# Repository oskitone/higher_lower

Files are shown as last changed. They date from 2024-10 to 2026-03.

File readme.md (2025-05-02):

# Higher Lower

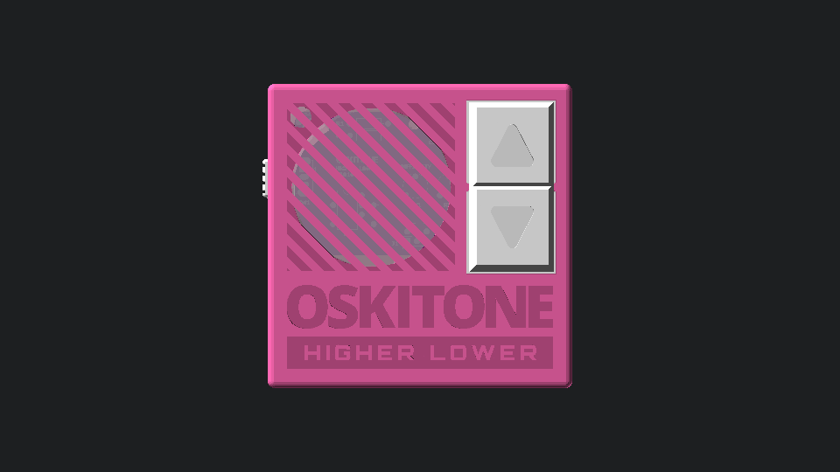
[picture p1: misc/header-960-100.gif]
Higher Lower game model animation


Higher Lower is a 3D-printed, screen-free, handheld electronic game about arbitrary musical intervals.

**DIY electronics kit:** [https://www.oskitone.com/product/higher-lower-game-diy-electronics-kit](https://www.oskitone.com/product/higher-lower-game-diy-electronics-kit)  
**Gameplay demo:** [https://vimeo.com/1075918437](https://vimeo.com/1075918437)  
**Assembly guide:** [https://oskitone.github.io/higher_lower](https://oskitone.github.io/higher_lower)

Obviously, I'd prefer you buy the kit from me. But, if circumstances prohibit, I've uploaded the [Higher Lower PCB to OSH Park](https://oshpark.com/shared_projects/yGNulCRo); please buy it from them with my blessing.

## How to play "Higher Lower"

Two different tones play. Is the second tone _higher_ or _lower_ than the first? The more guesses you get right, the harder it gets!

- Four guesses per round, ten rounds per game. Any wrong guess and the game resets.
- Your score is how many rounds have passed, and it's announced after each round as a series of happy trill noises.
- For a multiplayer game, hand off to the next player after each round. The last player to successfully complete their round wins.
- At the start of each new game, the "Higher Lower" theme song plays. It is a very good song.
- Upon completing all ten rounds of guesses and winning the game, the theme plays again, faster and _faster_ and **_faster_** until the machine finally resets into a new game at a harder difficulty setting.
- Adjust volume and game difficulty by opening the enclosure and adjusting trim potentiometers on the PCB.

## Schematic

Higher Lower schematic

In pursuit of a small BOM and quick assembly, there are a few concessions:

- There's no amplifier, just the IC to volume pot to cap to speaker. In theory, the speaker can draw more current than the chip can supply, causing it to overheat. In practice, it hasn't been an issue.
- There's a small .1uF bypass cap to smooth out power supply noise. Normally there's a big one too like the Scout's 220uF electrolytic cap. Again, in practice, its absence hasn't been an issue.

## Running, deploying

    ./run.sh -h

Requires arduino-cli to compile, [Ardens](https://github.com/tiberiusbrown/Ardens) to emulate, then a [Sparkfun programmer](https://www.sparkfun.com/products/9825) to upload. (Other programmers may work just as well, but I've only tested this one.)

### Deployment troubleshooting

- `Could not find USBtiny device`: Programmer not connected?
- `Programmer operation not supported`: Make sure board is getting full power. Try setting "CTRL" pot to its middle value. (Some pins to programmer are shared with game inputs.)

### Arduboy

You can also deploy to an [Arduboy](https://www.arduboy.com/) using the Arduino IDE. Play using the device's Up/Down buttons.

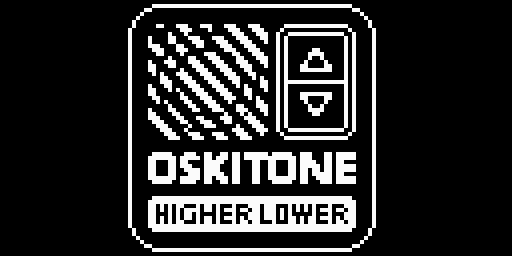
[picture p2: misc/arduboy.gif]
Higher Lower on Arduboy


(And you can play an online emulation of "Higher Lower" on the Arduboy [here](https://tiberiusbrown.github.io/Ardens/player.html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)!)

## 3D Models

higher_lower's 3D-printed models are written in OpenSCAD.

### Dependencies

Assumes `parts_cafe` and `scout` repos are in sibling directories and are _both up to date_ on the `main` branch. Here's how I've got it:

    \ oskitone
        \ higher_lower
        \ parts_cafe
        \ scout

You'll also need to install the [Orbitron](https://fonts.google.com/specimen/Orbitron) font.

### Building

STLs are generated with `make_stls.sh`. Run `./make_stls.sh -h` for full flags list.

## License

Designed by Oskitone. Please support future projects by purchasing from [Oskitone](https://www.oskitone.com/).

Creative Commons Attribution/Share-Alike, all text above must be included in any redistribution. See license.txt for additional details.

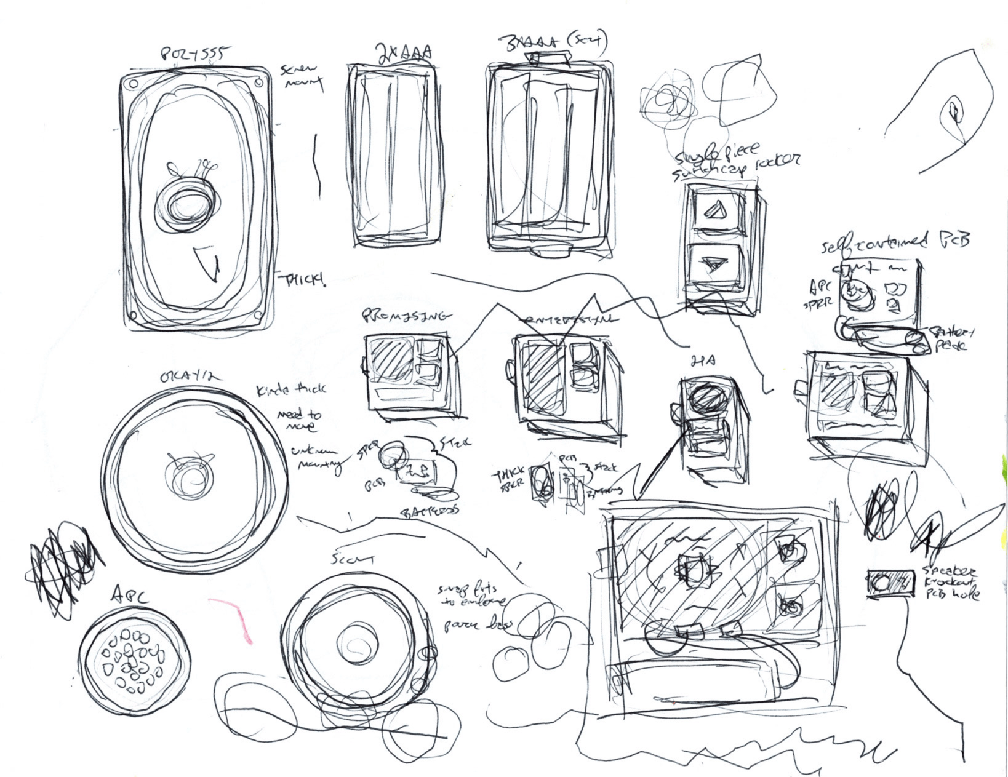
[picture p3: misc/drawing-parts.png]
Drawing, traces of speakers and batteries, prospective enclosure layouts


(drawing by me and my son)

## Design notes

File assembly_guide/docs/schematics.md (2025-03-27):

---
id: schematics
title: Schematics
description: Higher Lower circuit schematics
sidebar_label: Schematics
image: /img/final_product_1-004.jpg
hide_table_of_contents: true
---

Higher Lower schematic

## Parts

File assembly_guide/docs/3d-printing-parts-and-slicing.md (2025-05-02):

---
id: 3d-printing-parts-and-slicing
title: 3D-Printing
description: How to 3D-print your Higher Lower's parts.
sidebar_label: 3D-Printing
image: /img/3d_printed_parts.jpg
slug: /3d-printing-parts-and-slicing
---

:::note
If you bought a kit with 3D-printed parts included, you can skip this section, but do [open up the enclosure](opening-the-enclosure.md) and confirm you have all the right pieces ready before continuing.
:::

## Download

Download STLs of the models from [Printables](https://www.printables.com/model/1283695-higher-lower-handheld-electronic-game) or [Thingiverse](https://www.thingiverse.com/thing:7027239).

Higher Lower

## Slicing

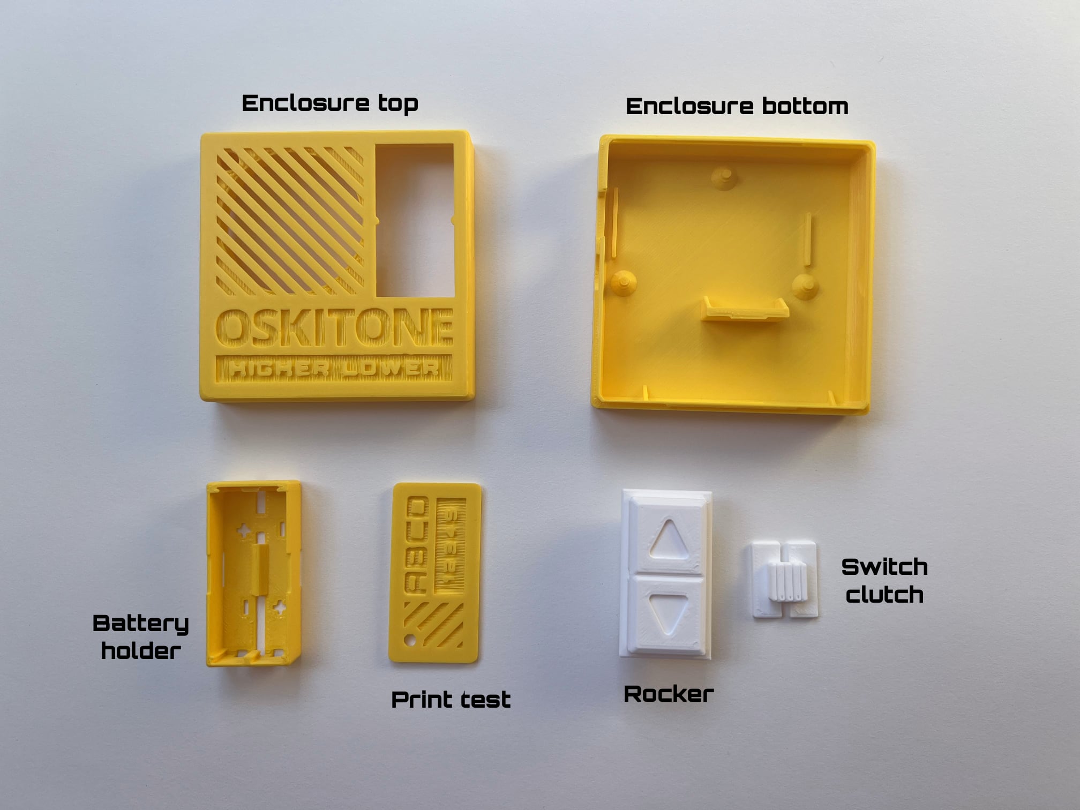
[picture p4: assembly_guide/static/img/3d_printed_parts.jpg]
3D-printed parts


There are six files to print, but only five are required. They'll take a little over four hours total.

| Part | Layer Height | Supports? | Estimated Time |
| --- | --- | --- | --- |
| enclosure_top | .2mm | No | 1.5hr |
| enclosure_bottom | .2mm | No | 1.5hr |
| battery_holder | .2mm | No | 30min |
| print_test (optional) | .2mm | No | 15min |
| rocker | .2mm | No | 30min |
| switch_clutch | .2mm | No | 10min |

:::info Optional but recommended
The `print_test` STL isn't used in assembly but is included to verify your printer's calibration and slicer settings. It's recommended to print it first before committing to the rest of the parts.
:::

The enclosure has engravings that print on the build plate and bridge on top. Adjust your slicer's bridging angle so they run up and down with the text:

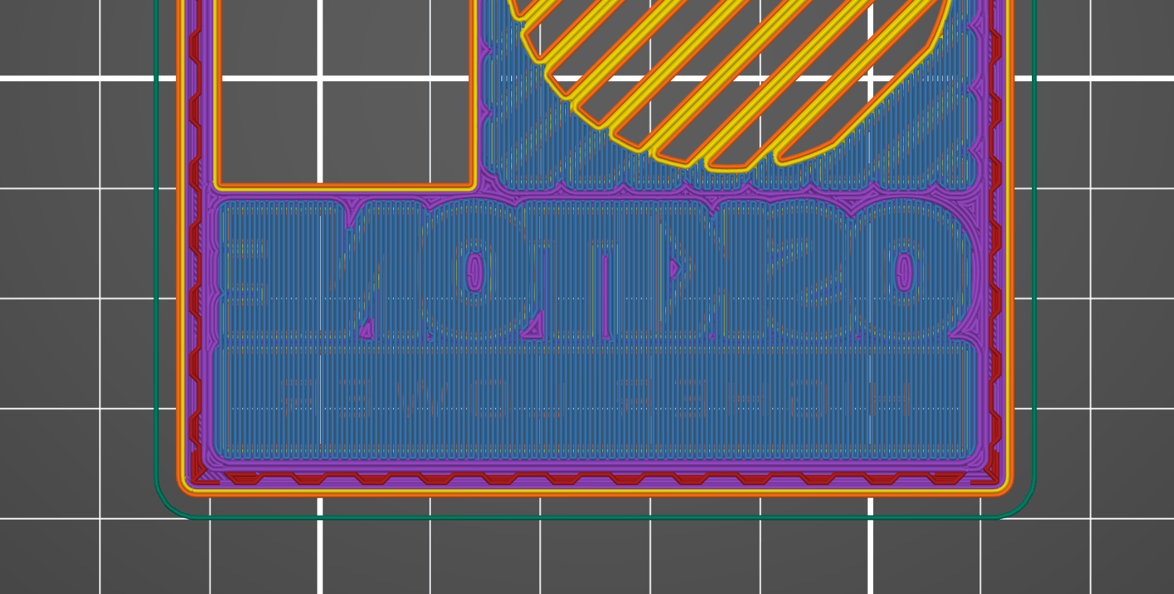
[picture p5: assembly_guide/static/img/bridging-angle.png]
bridging angle set correct


**Other notes:**

- Models assume Fused Deposition Modeling with a standard .4mm nozzle. Using a bigger nozzle will likely result in a loss of detail.
- The 3D-printed parts were designed using PLA. Other filament types like ABS are not recommended and will likely have fit or tolerance issues. (If you find that you need to drill or file your prints, that's a good sign there'll be other problems too.)
- 20% infill works well across all models.
- Any supports the models need they'll already have, they'll already be rotated to the correct orientation for printing, and they shouldn't need brims.
- Watch the first couple layers of the enclosure pieces while printing, especially around the text engravings -- if you see bad adhesion, stop the print to remedy the situation and start again.
- If the prints aren't fitting together well, check to see that the corners aren't bulging. See if your slicer has settings for "coasting" or "linear advance."

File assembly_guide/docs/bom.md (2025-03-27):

---
id: bom
title: Annotated BOM
description: Bill of Materials, annotated.
sidebar_label: Annotated BOM
slug: /bom
image: /img/kit_parts.jpg
hide_table_of_contents: true
---

| Designator | Quantity | Designation | Marking | Footprint |
| --- | --- | --- | --- | --- |
| C1 | 1 | .1uF | 104 | C_Disc_D5.0mm_W2.5mm_P5.00mm |
| C2 | 1 | 220uF | | CP_Radial_D8.0mm_P3.50mm |
| D1 | 1 | LED_RKGB | | LED_D5.0mm-4_RGB_Staggered_Pins |
| J1 | 1 | Conn_02x03 | | PinHeader_2x03_P2.54mm_Vertical |
| LS1 | 1 | AZ40R | | 40mm x 5mm |
| R1,R2 | 2 | 1k | Brown Black Red | R_Axial_DIN0207_L6.3mm_D2.5mm_P10.16mm_Horizontal |
| RV1 | 1 | 10k | 103 | Potentiometer_Piher_PT-6-V_Vertical-mirror |
| RV2 | 1 | 1k | 102 | Potentiometer_Piher_PT-6-V_Vertical-mirror |
| SW1 | 1 | SW_SPDT | | SW_Slide_SPDT_Angled_CK_OS102011MA1Q |
| SW2,SW3 | 2 | SW_SPST | | SW_PUSH_6mm |
| U1 | 1 | ATTINY85V + socket | | DIP-8_W7.62mm |

Also:

- 10" of 2-wire ribbon cables (or similar _small_ gauge, stranded wire)
  - 5" for BT1
  - 5" for LS1
- 4 battery terminal contacts for battery holder
  - 1 dual spring+button wire contacts (Keystone 181)
  - 1 tabbed spring contact (Keystone 5204)
  - 1 tabbed button contact (Keystone 5226)
- LED lightpipe
  - Hot glue stick, standard 1/4" diameter, cut to 1/8" length
  - An inch or so of electrical tape

Alternate speakers for the AZ40R:

- PSR-40N08A05-JQ
- AS04008MR-21-R
- CMS-4051-058SP

Any circular 8ohm speaker that matches the dimensions will probably work, thought you may find you need a bit of hot glue to hold it in place.

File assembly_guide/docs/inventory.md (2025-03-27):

---
id: inventory
title: Inventory
description: What you'll need to gather before getting started.
sidebar_label: Inventory
image: /img/kit_parts.jpg
slug: /inventory
---

#### Required

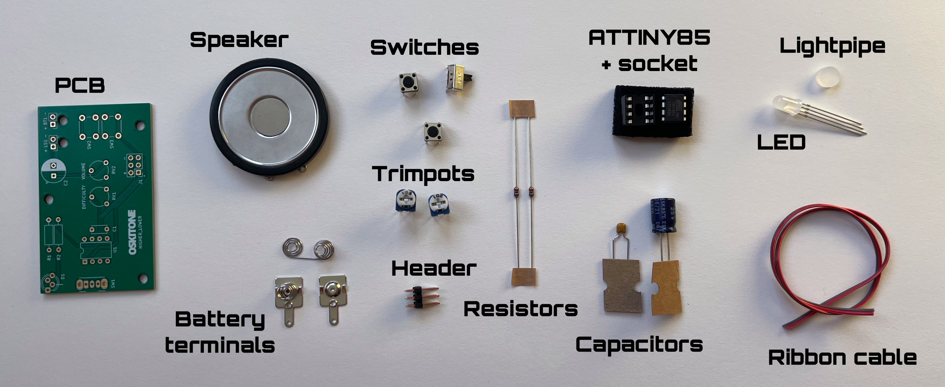
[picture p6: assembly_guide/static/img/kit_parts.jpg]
Higher Lower Game DIY Electronics Kit parts


- [Higher Lower Game DIY Electronics Kit](https://www.oskitone.com/product/higher-lower-game-diy-electronics-kit), 20 parts total
  - 1 PCB
  - 1 Speaker
  - 3 Battery terminals
  - 3 Switches
  - 2 Trimpots
  - 1 Header
  - 2 Resistors
  - 1 ATtiny85 chip + 1 chip socket
  - 2 Capacitors
  - 1 Lightpipe
  - 1 LED
  - 1 Ribbon cable
- [3D-printed parts](3d-printing-parts-and-slicing), 5 parts total
  - battery holder
  - enclosure bottom
  - enclosure top
  - rocker
  - switch clutch
- Soldering iron and solder specifically for electronics
- Wire stripper or cutters
- 2 AAA batteries

#### Recommended

- Needle nose pliers
- Multimeter for debugging
- PCB vice or “helping hands” holder
- “Solder sucker” or desoldering braid
- Black electrical tape
- Patience, patience, patience

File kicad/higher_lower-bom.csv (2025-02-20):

Id | Designator | Footprint | Quantity | Designation | Supplier and ref
1 | SW2,SW3 | SW_PUSH_6mm | 2 | SW_SPST
2 | C1 | C_Disc_D5.0mm_W2.5mm_P5.00mm | 1 | .1uF
3 | LS1 | PinHeader_1x02_P2.54mm_Vertical | 1 | Speaker
4 | U1 | DIP-8_W7.62mm | 1 | ATTINY85V-10PU
5 | SW1 | SW_Slide_SPDT_Angled_CK_OS102011MA1Q | 1 | SW_SPDT
6 | BT1 | PinHeader_1x02_P2.54mm_Vertical | 1 | 1.8V-5.5V
7 | D1 | LED_D5.0mm-4_RGB_Staggered_Pins | 1 | LED_RKGB
8 | RV2 | Potentiometer_Piher_PT-6-V_Vertical-mirror | 1 | 1k
9 | Ref** | branding-15mm_wide | 1 | Val**
10 | RV1 | Potentiometer_Piher_PT-6-V_Vertical-mirror | 1 | 10k
11 | C2 | CP_Radial_D8.0mm_P3.50mm | 1 | 220uF
12 | J1 | PinHeader_2x03_P2.54mm_Vertical | 1 | Conn_02x03
13 | R2,R1 | R_Axial_DIN0207_L6.3mm_D2.5mm_P10.16mm_Horizontal | 2 | 1k

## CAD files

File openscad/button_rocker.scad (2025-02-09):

include <../../parts_cafe/openscad/cap_blank.scad>;
include <../../parts_cafe/openscad/engraving.scad>;
include <../../parts_cafe/openscad/flat_top_rectangular_pyramid.scad>;

// NOTES: must be well less than SCOUT_DEFAULT_GUTTER,
// chamfer is eyeballed against ENCLOSURE_INNER_CHAMFER
ROCKER_BRIM_SIZE = 2;
ROCKER_BRIM_HEIGHT = 1.2;
ROCKER_BRIM_CHAMFER = .6;

BUTTON_ROCKER_TOP_CHAMFER = 2;

ROCKER_ENCLOSURE_FIXTURE_DEPTH = .4;

function get_rocker_switch_center(
    xy = [0,0],
    offset = [0,0]
) = ([
    xy.x - offset.x,
    xy.y - offset.y,
]);

module button_rocker(
    width, length, height,

    switch_centers = [],
    actuator_cavity_height =
        SPST_ACTUATOR_HEIGHT_OFF_PCB - SPST_BASE_DIMENSIONS.z
        - SPST_CONSERVATIVE_TRAVEL,

    plunge = 0,

    xy_clearance = 0,
    z_clearance = 0,

    brim_size = ROCKER_BRIM_SIZE,
    brim_height = ROCKER_BRIM_HEIGHT,
    brim_chamfer = ROCKER_BRIM_CHAMFER,

    fixture_retraction = 0,
    fixture_cavity_height = 2,

    fillet = 0,
    chamfer = ENCLOSURE_ENGRAVING_CHAMFER,

    tolerance = 0,

    outer_color = undef,
    cavity_color = undef,

    quick_preview = false
) {
    e = .0481;

    brim_dimensions = [
        width + brim_size * 2,
        length * 2 + xy_clearance + brim_size * 2,
        brim_height
    ];

    actuator_cavitiy_inner_diameter = SPST_ACTUATOR_DIAMETER
        + tolerance * 4; // NOTE: doubled to be intentionally loose
    actuator_cavitiy_outer_diameter = actuator_cavitiy_inner_diameter + chamfer * 2;

    minimum_walled_actuator_cavities_width =
        actuator_cavitiy_outer_diameter + ENCLOSURE_INNER_WALL * 2;

    plunge = plunge + actuator_cavity_height;
    offset = min(
        (brim_dimensions.x - minimum_walled_actuator_cavities_width) / 2,
        plunge // ie, a 45 degree chamfer
    );

    module _engraving(y, rotation, size = min(width, length) * .5) {
        translate([width / 2, y, height - ENCLOSURE_ENGRAVING_DEPTH]) {
            rotate([0, 0, rotation]) engraving(
                svg = "../misc/arrow.svg",
                resize = [size, size],
                bleed = quick_preview ? 0 : ENCLOSURE_ENGRAVING_BLEED,
                height = ENCLOSURE_ENGRAVING_DEPTH + e,
                center = true,
                chamfer =  quick_preview ? 0 : chamfer
            );
        }
    }

    module _actuator_cavities($fn = quick_preview ? 6 : 24) {
        for (xy = switch_centers) {
            translate([xy.x, xy.y, -(plunge + e)]) {
                cylinder(
                    d = actuator_cavitiy_inner_diameter,
                    h = actuator_cavity_height + e
                );

                cylinder(
                    d1 = actuator_cavitiy_outer_diameter,
                    d2 = actuator_cavitiy_inner_diameter,
                    h = chamfer + e
                );
            }
        }
    }

    module _enclosure_fixture_cavity() {
        radius = ROCKER_ENCLOSURE_FIXTURE_DEPTH + fixture_retraction
            + tolerance * 4; // NOTE: again, doubled to be intentionally loose

        for (x = [-(fixture_retraction + tolerance), width + fixture_retraction]) {
            translate([x, length + xy_clearance / 2, brim_dimensions.z]) {
                cylinder(
                    r = radius,
                    h = fixture_cavity_height,
                    $fn = 8
                );
            }
        }
    }

    difference() {
        color(outer_color) {
            for (y = [0, length + xy_clearance]) {
                translate([0, y, -e]) {
                    cap_blank(
                        dimensions = [width, length, height + e],
                        contact_dimensions = [
                            width - SCOUT_DEFAULT_GUTTER,
                            length - SCOUT_DEFAULT_GUTTER,
                            BUTTON_ROCKER_TOP_CHAMFER
                        ],

                        fillet = fillet
                    );
                }
            }

            translate([-brim_size, -brim_size, 0]) {
                cube([
                    brim_dimensions.x,
                    brim_dimensions.y,
                    brim_dimensions.z - brim_chamfer + e
                ]);

                translate([0, 0, brim_dimensions.z - brim_chamfer]) {
                    flat_top_rectangular_pyramid(
                        top_width = brim_dimensions.x - brim_chamfer * 2,
                        top_length = brim_dimensions.y - brim_chamfer * 2,
                        bottom_width = brim_dimensions.x,
                        bottom_length = brim_dimensions.y,
                        height = brim_chamfer
                    );
                }
            }

            translate([-brim_size + offset, -brim_size + offset, -plunge]) {
                flat_top_rectangular_pyramid(
                    top_width = brim_dimensions.x,
                    top_length = brim_dimensions.y,
                    bottom_width = brim_dimensions.x - offset * 2,
                    bottom_length = brim_dimensions.y - offset * 2,
                    height = plunge + e
                );
            }
        }

        color(cavity_color) {
            _engraving(length + xy_clearance + length / 2, 0);
            _engraving(length / 2, 180);
            _actuator_cavities();
            _enclosure_fixture_cavity();
        }
    }
}

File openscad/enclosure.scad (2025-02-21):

include <../../parts_cafe/openscad/battery_holder_fixtures.scad>;
include <../../parts_cafe/openscad/diagonal_grill.scad>;
include <../../parts_cafe/openscad/enclosure_engraving.scad>;
include <../../parts_cafe/openscad/enclosure.scad>;
include <../../parts_cafe/openscad/flat_top_rectangular_pyramid.scad>;
include <../../parts_cafe/openscad/pcb_mounting_columns.scad>;
include <../../parts_cafe/openscad/ring.scad>;

include <pcb.scad>;

SWITCH_CLUTCH_GRIP_LENGTH = 10;

DEFAULT_ROUNDING = 24;
HIDEF_ROUNDING = 120;

module enclosure(
    show_top = true,
    show_bottom = true,

    dimensions = [0,0,0],
    bottom_height = 0,
    top_height = 0,

    control_clearance = 0,

    pcb_position = [0,0,0],
    led_position_on_pcb = PCB_LED_POSITION,

    speaker_position = [0,0,0],
    speaker_grill_dimensions = [0,0,0],
    speaker_grill_position = [0,0,0],

    lightpipe_position = [0,0],

    button_dimensions = [0,0],
    button_rocker_position = [0,0,0],
    rocker_xy_clearance = 0,

    battery_holder_dimensions = [0,0,0],
    battery_holder_position = [0,0,0],

    label_gutter = 0,

    top_engraving_dimensions = [0,0],
    top_engraving_position = [0,0],
    top_engraving_model_text_size = 3.8,
    top_engraving_model_length = ENCLOSURE_ENGRAVING_LENGTH,

    lip_height = ENCLOSURE_LIP_HEIGHT,

    fillet = ENCLOSURE_FILLET,
    inner_chamfer = ENCLOSURE_INNER_CHAMFER,

    pcb_width = 0,
    pcb_length = 0,
    pcb_height = PCB_HEIGHT,

    pcb_post_hole_positions = [],

    switch_clutch_grip_height = 0,
    switch_clutch_web_length_extension = 0,

    tolerance = 0,

    outer_color = undef,
    cavity_color = undef,

    chamfer = .4,
    show_dfm = true,

    quick_preview = true
) {
    e = .03183;

    cavity_z = dimensions.z - ENCLOSURE_FLOOR_CEILING - e;
    cavity_height = ENCLOSURE_FLOOR_CEILING + e * 2;

    speaker_cavity_diameter = SPEAKER_DIAMETER + tolerance * 2;

    switch_clutch_aligner_length =
        SWITCH_CLUTCH_GRIP_LENGTH + SWITCH_ACTUATOR_TRAVEL
        + switch_clutch_web_length_extension * 2;
    switch_clutch_aligner_y = pcb_position.y + PCB_SWITCH_Y
            + SWITCH_BASE_LENGTH / 2
            - switch_clutch_aligner_length / 2;

    under_pcb_fixture_height = pcb_position.z - ENCLOSURE_FLOOR_CEILING;

    module _c(
        diameter,
        height,
        chamfer = chamfer,
        $fn = quick_preview ? undef : HIDEF_ROUNDING
    ) {
        cylinder(
            d = diameter,
            h = height
        );

        if (show_dfm && chamfer > 0) {
            translate([0, 0, height - chamfer]) {
                cylinder(
                    d1 = diameter,
                    d2 = diameter + chamfer * 2,
                    h = chamfer
                );
            }
        }
    }

    module _speaker_grill(
        depth = ENCLOSURE_ENGRAVING_DEPTH
    ) {
        translate([
            speaker_grill_position.x,
            speaker_grill_position.y,
            dimensions.z - depth
        ]) {
            render() diagonal_grill(
                speaker_grill_dimensions.x,
                speaker_grill_dimensions.y,
                depth + e,
                size = DIAGONAL_GRILL_SIZE
            );
        }
    }

    module _speaker_cavity() {
        z = dimensions.z - ENCLOSURE_FLOOR_CEILING;

        render() intersection() {
            translate([speaker_position.x, speaker_position.y, z - e]) {
                _c(
                    speaker_cavity_diameter,
                    ENCLOSURE_FLOOR_CEILING + e * 2,
                    chamfer = 0
                );
            }

            _speaker_grill(ENCLOSURE_FLOOR_CEILING + e * 2);
        }
    }

    module _bottom_engraving(
        brand_length = 8,
        make_y = dimensions.y * .25
    ) {
        render() enclosure_engraving(
            size = brand_length,
            center = true,
            position = [dimensions.x / 2, make_y],
            bottom = true,
            quick_preview = quick_preview,
            enclosure_height = dimensions.z
        );
    }

    module _half(height, lip) {
        enclosure_half(
            width = dimensions.x,
            length = dimensions.y,
            height = height,
            add_lip = lip,
            remove_lip = !lip,
            lip_height = lip_height,
            fillet = quick_preview ? 0 : fillet,
            inner_chamfer = quick_preview ? 0 : inner_chamfer,
            tolerance = tolerance * 1.5, // intentionally kinda loose
            include_tongue_and_groove = true,
            tongue_and_groove_snap = [.5, 1, .5, 1],
            tongue_and_groove_pull = .3,
            include_disassembly_dimples = true,
            include_disassembly_wedges = true,
            outer_color = outer_color,
            cavity_color = cavity_color,
            $fn = quick_preview ? undef : DEFAULT_ROUNDING
        );
    }

    module _bottom_pcb_fixtures(
        button_support_length = 15 // NOTE: eyeballed!
    ) {
        pcb_mounting_columns(
            pcb_position = pcb_position,
            wall = ENCLOSURE_INNER_WALL,
            pcb_screw_hole_positions = [],
            pcb_post_hole_positions = pcb_post_hole_positions,
            tolerance = tolerance,
            enclosure_floor_ceiling = ENCLOSURE_FLOOR_CEILING,
            pcb_hole_diameter = PCB_HOLE_DIAMETER,
            registration_nub_height = PCB_HEIGHT,
            support_web_length = (pcb_position.z - ENCLOSURE_FLOOR_CEILING) / 2,
            quick_preview = quick_preview
        );

        translate([
            button_rocker_position.x
                + (button_dimensions.x - ENCLOSURE_INNER_WALL) / 2,
            button_rocker_position.y
                + button_dimensions.y + rocker_xy_clearance / 2
                - button_support_length / 2,
            ENCLOSURE_FLOOR_CEILING - e
        ]) {
            cube([
                ENCLOSURE_INNER_WALL,
                button_support_length,
                pcb_position.z - ENCLOSURE_FLOOR_CEILING + e
            ]);
        }
    }

    module _switch_clutch_deobstruction_cavity(
        width = 3 // NOTE: arbitrary
    ) {
        translate([
            pcb_position.x - width,
            switch_clutch_aligner_y - tolerance - e,
            -e
        ]) {
            cube([
                width,
                switch_clutch_aligner_length
                    + tolerance * 2 + e * 2,
                dimensions.z + e * 2
            ]);
        }
    }

    module _speaker_fixture() {
        difference() {
            translate(speaker_position) {
                speaker_fixture(
                    height = SPEAKER_HEIGHT + e,
                    wall = ENCLOSURE_INNER_WALL,

                    tab_cavity_count = 2,
                    tab_cavity_rotation = 0,

                    tolerance = tolerance,
                    quick_preview = quick_preview
                );
            }

            // NOTE: Defensive! Only needed when fixture flows
            // into clutch's area
            _switch_clutch_deobstruction_cavity();
        }
    }

    module _top_engraving() {
        brand_length = top_engraving_dimensions.x * OSKITONE_LENGTH_WIDTH_RATIO;
        placard_length = top_engraving_dimensions.y
            - brand_length - label_gutter;

        render() enclosure_engraving(
            size = brand_length,
            position = [
                top_engraving_position.x,
                top_engraving_position.y
                    + label_gutter
                    + placard_length
            ],
            bottom = false,
            center = false,
            quick_preview = quick_preview,
            enclosure_height = dimensions.z
        );

        render() enclosure_engraving(
            // HACK: kerning
            string = "H\u2009I\u2009G\u2009H\u2009E\u2009R\u2009 \u2009L\u2009O\u2009W\u2009E\u2009R",
            size = top_engraving_model_text_size,
            position = [
                top_engraving_position.x + top_engraving_dimensions.x / 2,
                top_engraving_position.y + placard_length / 2
            ],
            placard = [
                top_engraving_dimensions.x,
                placard_length
            ],
            bottom = false,
            center = true,
            quick_preview = quick_preview,
            enclosure_height = dimensions.z
        );
    }

    module _button_rocker_cavity() {
        gutter = control_clearance + tolerance;

        width = button_dimensions.x + gutter * 2;
        length = button_dimensions.y * 2
            + rocker_xy_clearance + gutter * 2;
        height = ENCLOSURE_FLOOR_CEILING + e * 2;

        translate([
            button_rocker_position.x - gutter,
            button_rocker_position.y - gutter,
            dimensions.z - ENCLOSURE_FLOOR_CEILING - e
        ]) {
            difference() {
                cube([width, length, height]);
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

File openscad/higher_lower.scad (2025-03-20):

include <../../parts_cafe/openscad/batteries-aaa.scad>;
include <../../parts_cafe/openscad/battery_holder.scad>;
include <../../parts_cafe/openscad/console.scad>;
include <../../parts_cafe/openscad/lightpipe.scad>;
include <../../parts_cafe/openscad/print_test.scad>;
include <../../parts_cafe/openscad/socket-35PM2A.scad>;
include <../../parts_cafe/openscad/speaker-AZ40R.scad>;

use <../../scout/openscad/switch_clutch.scad>;

include <button_rocker.scad>;
include <enclosure.scad>;
include <pcb.scad>;

// The Scout derives its default_gutter/keys_x as ENCLOSURE_WALL + key_gutter
// Here, we'll just use it statically to match.
SCOUT_DEFAULT_GUTTER = 3.4;
OUTER_GUTTER = 5;

module higher_lower(
    width = 25.4 * 3,
    length = 25.4 * 3,
    height = 25.4 * 1,

    pcb_width = PCB_WIDTH,
    pcb_length = PCB_LENGTH,

    show_enclosure_bottom = true,
    show_battery_holder = true,
    show_batteries = true,
    show_pcb = true,
    show_switch_clutch = true,
    show_speaker = true,
    show_rocker = true,
    show_lightpipe = true,
    show_enclosure_top = true,
    show_print_test = false,

    show_clearance = false,

    button_exposure = 3,
    switch_exposure = 2,
    control_clearance = .6,

    outer_gutter = OUTER_GUTTER,
    default_gutter = SCOUT_DEFAULT_GUTTER,
    rocker_xy_clearance = SCOUT_DEFAULT_GUTTER / -2,
    rocker_z_clearance = .8,
    label_gutter = 2,

    accessory_fillet = 1,

    pcb_component_to_outer_part_clearance = 2,
    pcb_bottom_clearance = PCB_BOTTOM_CLEARANCE,

    pcb_post_hole_positions = [
        PCB_HOLE_POSITIONS[0],
        PCB_HOLE_POSITIONS[2],
        PCB_HOLE_POSITIONS[4],
    ],

    battery_count = 2,

    tolerance = 0,

    enclosure_outer_color = "#FF69B4",
    enclosure_cavity_color = "#CC5490",

    control_outer_color = "#FFFFFF",
    control_cavity_color = "#EEEEEE",

    side_switch_position = round($t),
    switch_clutch_web_length_extension = 4, // NOTE: eyeballed!

    quick_preview = true
) {
    e = .00319;

    available_width = width - outer_gutter * 2;
    available_length = length - outer_gutter * 2;

    // NOTE: 2:1 ratio here assumes portrait/square enclosure dimensions.
    // It will look odd if enclosure width > length.
    speaker_grill_size = (width - outer_gutter * 2 - default_gutter) / 3 * 2;
    button_width = speaker_grill_size / 2;
    button_length = (speaker_grill_size - rocker_xy_clearance) / 2;

    battery_holder_dimensions = get_battery_holder_dimensions(
        battery_count,
        tolerance
    );
    battery_holder_position = [
        (width - battery_holder_dimensions.x) * (2/3),
        ENCLOSURE_WALL + tolerance * 2,
        ENCLOSURE_FLOOR_CEILING
    ];

    speaker_grill_position = [
        outer_gutter,
        length - speaker_grill_size - outer_gutter
    ];
    speaker_position = [
        speaker_grill_position.x + speaker_grill_size / 2,
        speaker_grill_position.y + speaker_grill_size / 2,
        height - ENCLOSURE_FLOOR_CEILING - SPEAKER_HEIGHT
    ];

    // NOTE: ie, the closest it can get to speaker
    radius_difference = SPEAKER_DIAMETER / 2 + LIGHTPIPE_DIAMETER / 2
        + tolerance * 2 + ENCLOSURE_INNER_WALL;
    bump_xy = sqrt(pow(radius_difference, 2) / 2);
    lightpipe_position = [
        speaker_position.x - bump_xy,
        speaker_position.y + bump_xy,
        height - ENCLOSURE_FLOOR_CEILING - LIGHTPIPE_LENGTH
    ];

    pcb_position = [
        lightpipe_position.x - PCB_LED_POSITION.x,
        lightpipe_position.y - PCB_LED_POSITION.y,
        max(
            ENCLOSURE_FLOOR_CEILING + pcb_bottom_clearance,
            min(
                speaker_position.z
                    - (pcb_component_to_outer_part_clearance + PCB_TOP_CLEARANCE_UNDER_SPEAKER)
                    - PCB_HEIGHT,
                lightpipe_position.z
                    - pcb_component_to_outer_part_clearance
                    - LED_HEIGHT - PCB_Z_OFF_PCB
                    - PCB_HEIGHT
            )
        )
    ];

    button_rocker_position = [
        speaker_grill_position.x + speaker_grill_size + default_gutter,
        speaker_grill_position.y,
        height - ENCLOSURE_FLOOR_CEILING - ROCKER_BRIM_HEIGHT
            - rocker_z_clearance
    ];
    button_height = ROCKER_BRIM_HEIGHT + ENCLOSURE_FLOOR_CEILING + button_exposure
        + rocker_z_clearance;

    switch_clutch_grip_height = height
        - (pcb_position.z + PCB_HEIGHT + SWITCH_ACTUATOR_Z) * 2;

    enclosure_bottom_height = height / 2;
    enclosure_top_height = height - enclosure_bottom_height;

    echo("Enclosure", width / 25.4, length / 25.4, height / 25.4);
    echo("PCB", pcb_width / 25.4, pcb_length / 25.4);
    echo("PCB bottom clearance", pcb_position.z - ENCLOSURE_FLOOR_CEILING);
    echo("Button", button_width / 25.4, button_length / 25.4);
    echo("Speaker",
        SPEAKER_DIAMETER / 2,
        get_speaker_fixture_diameter(tolerance),
        [
            // consts here are bottom left of PCB in KiCad
            (speaker_position.x - pcb_position.x) + 101.6,
            114.3 - (speaker_position.y - pcb_position.y),
        ]
    );

    if (show_batteries || show_battery_holder) {
        translate([
            BATTERY_HOLDER_DEFAULT_WALL + tolerance + battery_holder_position.x,
            battery_holder_position.y + BATTERY_HOLDER_DEFAULT_WALL + tolerance,
            battery_holder_position.z + BATTERY_HOLDER_DEFAULT_FLOOR + e
        ]) {
            if (show_batteries) {
                % battery_array(
                    count = battery_count
                );
            }

            if (show_battery_holder) {
                battery_holder(
                    wall = BATTERY_HOLDER_DEFAULT_WALL,
                    floor = BATTERY_HOLDER_DEFAULT_FLOOR,
                    tolerance = tolerance,
                    count = battery_count,

                    fillet = quick_preview ? 0 : BATTERY_HOLDER_FILLET,

                    include_wire_relief_hitches = false,
                    include_wire_channel = true,
                    use_wire_channel_as_relief = true,

                    outer_color = enclosure_outer_color,
                    cavity_color = enclosure_cavity_color,

                    quick_preview = quick_preview
                );
            }
        }
    }

    if (show_rocker) {
        offset = [
            button_rocker_position.x - pcb_position.x,
            button_rocker_position.y - pcb_position.y
        ];

        switch_centers = [
            get_rocker_switch_center(PCB_SWITCH_CENTERS[0], offset),
            get_rocker_switch_center(PCB_SWITCH_CENTERS[1], offset),
        ];

        translate(button_rocker_position) {
            button_rocker(
                button_width, button_length, button_height,
                switch_centers = switch_centers,
                plunge = button_rocker_position.z
                    - (pcb_position.z + PCB_HEIGHT + SPST_ACTUATOR_HEIGHT_OFF_PCB),
                xy_clearance = rocker_xy_clearance,
                brim_height = ROCKER_BRIM_HEIGHT,
                fixture_retraction = control_clearance,
                fixture_cavity_height = ENCLOSURE_FLOOR_CEILING
                    + rocker_z_clearance * 2,
                fillet = quick_preview ? 0 : accessory_fillet,
                tolerance = tolerance,
                outer_color = control_outer_color,
                cavity_color = control_cavity_color,
                quick_preview = quick_preview
            );
        }
    }

    if (show_enclosure_bottom || show_enclosure_top) {
        enclosure(
            show_top = show_enclosure_top,
            show_bottom = show_enclosure_bottom,

            dimensions = [width, length, height],
            bottom_height = enclosure_bottom_height,
            top_height = enclosure_top_height,

            control_clearance = control_clearance,

            pcb_position = pcb_position,

            speaker_position = speaker_position,
            speaker_grill_dimensions = [speaker_grill_size, speaker_grill_size],
            speaker_grill_position = speaker_grill_position,

            lightpipe_position = lightpipe_position,

            button_dimensions = [button_width, button_length],
            button_rocker_position = button_rocker_position,
            rocker_xy_clearance = rocker_xy_clearance,

            battery_holder_dimensions = battery_holder_dimensions,
            battery_holder_position = battery_holder_position,

            label_gutter = label_gutter,

            top_engraving_dimensions = [
                available_width,
                available_length - speaker_grill_size - default_gutter
            ],
            top_engraving_position = [outer_gutter, outer_gutter],

            pcb_width = pcb_width,
            pcb_length = pcb_length,

            pcb_post_hole_positions = pcb_post_hole_positions,
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

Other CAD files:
openscad/pcb.scad

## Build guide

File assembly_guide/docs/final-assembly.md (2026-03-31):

---
id: final-assembly
title: Final assembly
description: How to assemble finish the Higher Lower's assembly.
sidebar_label: Final assembly
image: /img/enclosure_bottom_switch_clutch-025.jpg
slug: /final-assembly
---

:::note
You're almost done! Take your time to follow the directions in order.
:::

:::tip Optional
It's not pictured in the guide, but you might like to wrap some electrical tape around the LED so it shines _up_ but not _out_. This will prevent it from lighting up the enclosure instead of just its lightpipe.
:::

## Steps

1. Insert the **lightpipe** into its cavity on the **enclosure top**. A pair of pliers can help get it in there.
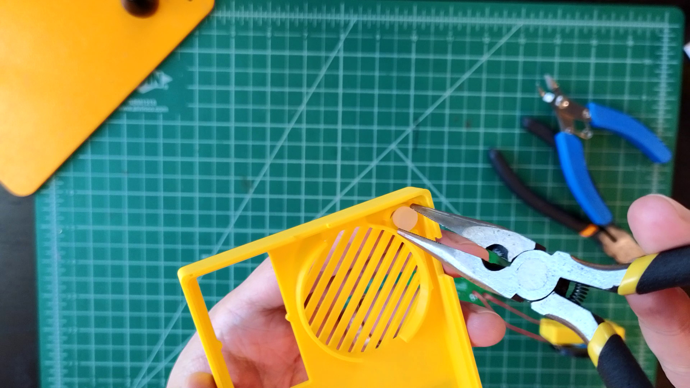
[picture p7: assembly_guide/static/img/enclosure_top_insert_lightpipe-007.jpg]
enclosure top insert lightpipe
   
2. Insert PCB into the **enclosure bottom**, nestled onto its posts.
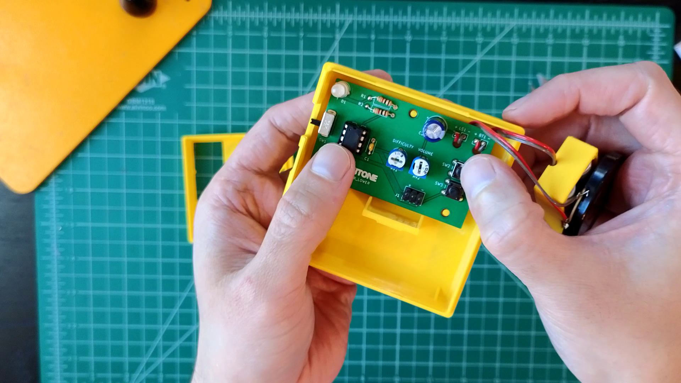
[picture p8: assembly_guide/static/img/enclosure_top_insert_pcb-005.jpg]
enclosure top insert pcb
   
3. Insert **battery holder** into its hitch on the **enclosure bottom**.
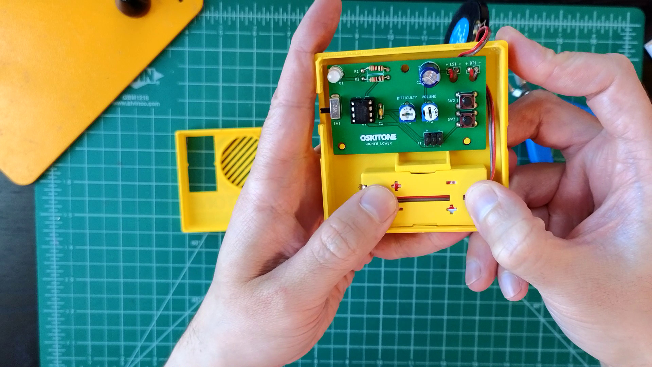
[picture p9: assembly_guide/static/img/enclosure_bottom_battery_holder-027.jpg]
enclosure bottom battery holder
   
   Rotate the holder so its wires are on the right side and the batteries are facing down. (The batteries can face up too, but they might pop out of the holder if the game is dropped.)
4. Pop **speaker** into place on the **enclosure top**.
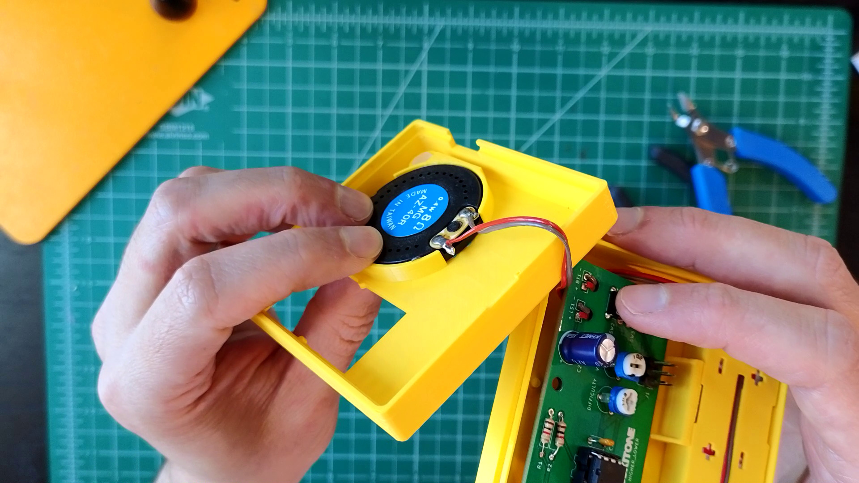
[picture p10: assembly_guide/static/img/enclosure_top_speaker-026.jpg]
enclosure top speaker
   
5. Place the **switch clutch** into the **enclosure bottom** onto **SW1**'s actuator, along the left edge of PCB.
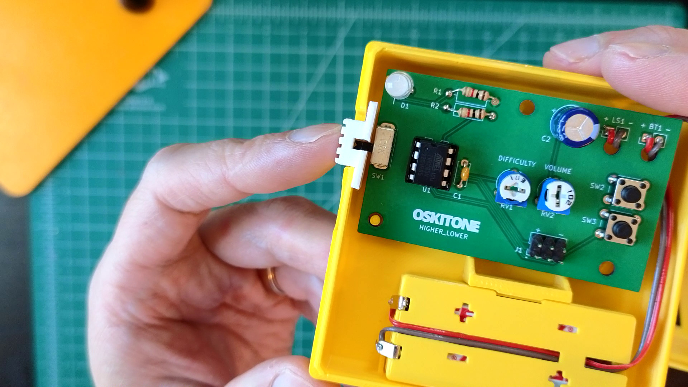
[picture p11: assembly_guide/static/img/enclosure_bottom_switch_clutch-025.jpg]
enclosure bottom switch clutch
   
6. Pop the **button rocker** into its cavity on the **enclosure top**. Its fixture is intentionally a little loose and that's okay.
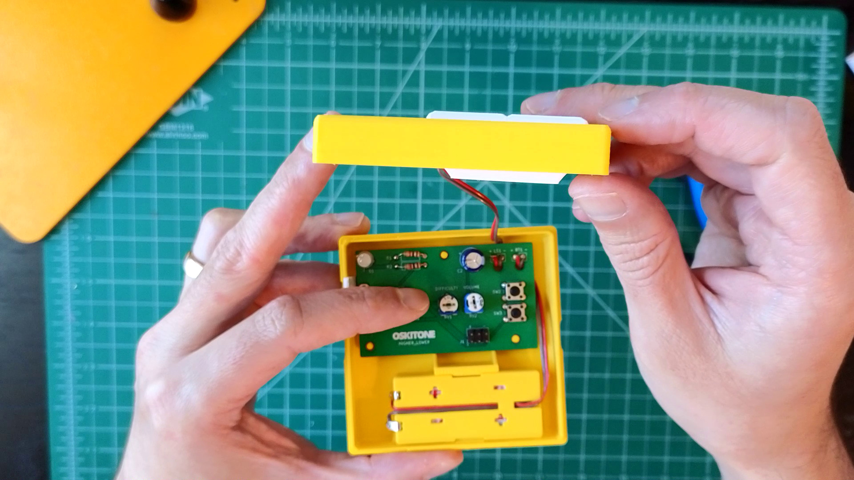
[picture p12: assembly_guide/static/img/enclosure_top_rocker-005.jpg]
enclosure top rocker
   
7. Align enclosure top and bottom, then firmly squeeze til the enclosure snaps shut. It's a tight fit; be brave!
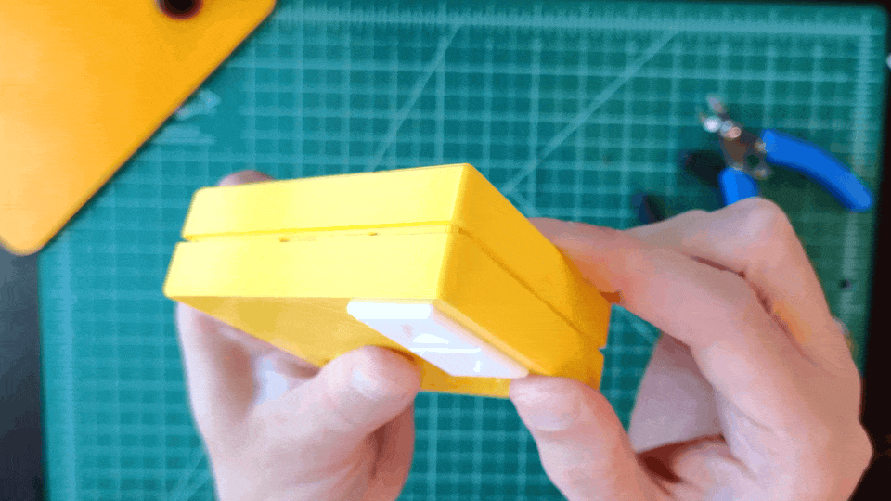
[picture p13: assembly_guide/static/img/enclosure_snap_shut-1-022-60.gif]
enclosure_snap_shut
   
8. Slide the **switch clutch** to turn the power on and check that the **button rocker** isn't unintentionally holding either of its switches down.

If that works, you're all done!

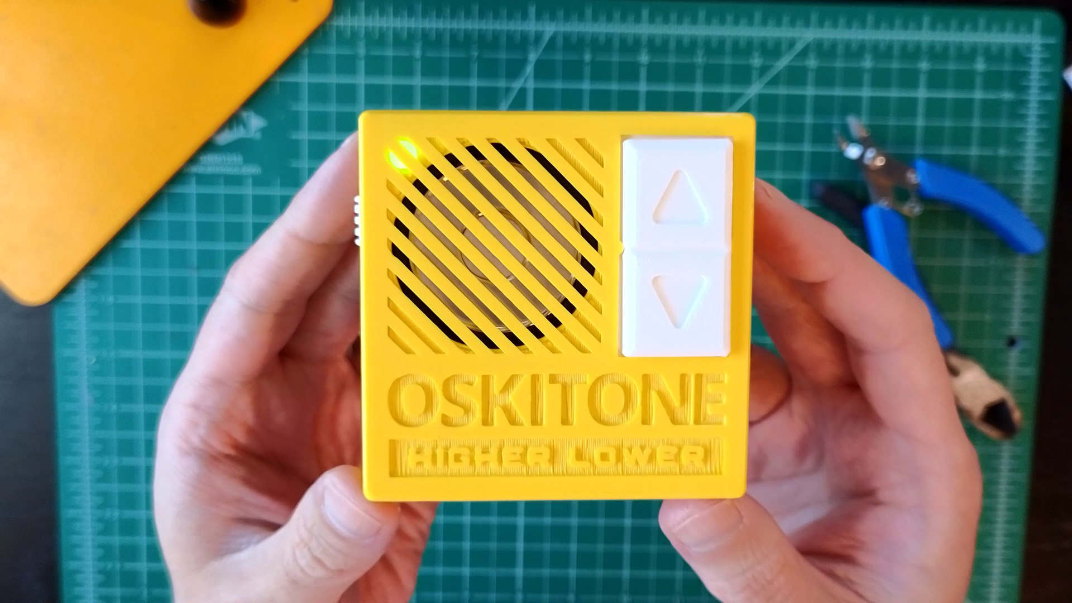
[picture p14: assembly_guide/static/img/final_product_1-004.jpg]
Higher Lower, final product


## Assembly troubleshooting

- Enclosure halves don't fit together well? [Pop the enclosure open](opening-the-enclosure.md) and check...
  - Are any wires in the way?
  - Is the rocker all the way into its fixture?
  - A gap near the lightpipe could mean the lightpipe is too long or isn't in all the way. Push it in, trim the excess, etc.
- Other oddities
  - Is the PCB functioning as expected? If not, go back through the soldering instructions and verify each step's test passes.
  - Something else? [Ask](https://www.oskitone.com/contact)!

## What's next

### Feedback

When you can, please [let me know](https://www.oskitone.com/contact) how it went for you:

- **What did you like?** Did you have fun?!
- Not including printing time, about **how long did it take?**
- **How'd the kit show up?** Were there any parts missing or damaged? Or any **problems with the instructions**?

I act and rely on customers' feedback to make the next products even better. Even just knowing that you got it done successfully is valuable feedback, so I do want to hear from you. Thank you so much!

### Share your make

Like Higher Lower? I'd love to have you share that!

- If you 3D-printed it at home, share your make on the [Printables](https://www.printables.com/model/1283695-higher-lower-handheld-electronic-game) or [Thingiverse](https://www.thingiverse.com/thing:7027239) page where you downloaded the models. It's a good signal to other potential makers to see successful makes.
- Tell your friends, post on social, etc. You know the deal!

### Follow along

I run an informal [email list](https://www.oskitone.com/mailing-list) to update folks on projects, notify when new products hit the store, and get early feedback and share ideas. If you're interested in what's next with Oskitone, it's the best way to stay updated.

<iframe
  scrolling="no"
  style={{width: "100%", height: "135px", border: "none"}}
  src="https://buttondown.com/oskitone?as_embed=true"
></iframe>

Powered by [Buttondown](https://buttondown.com/refer/oskitone). Read previous emails in the archive [here](https://buttondown.com/oskitone/archive/).

And, of course, follow [@oskitone on Instagram](https://www.instagram.com/oskitone).

### Further reading

For the curious, I've written [a blog post where you can read more about Higher Lower and its development process](https://blog.tommy.sh/posts/higher-lower/).

Each Oskitone product gets its own blog post, so dig around in there and see if there's anything else you find interesting.

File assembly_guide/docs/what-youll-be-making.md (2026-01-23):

---
id: what-youll-be-making
title: Oskitone Higher Lower Assembly Guide
sidebar_label: What You'll Be Making
description: How to solder and assemble the Oskitone Higher Lower Electronics Kit
image: /img/assembly-4-40-500.gif
slug: /
---

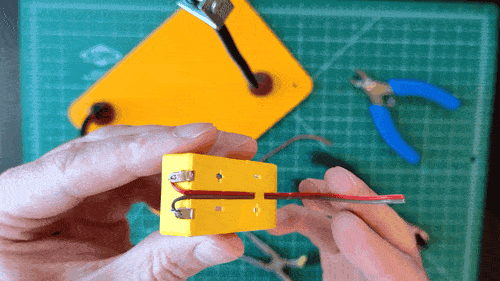
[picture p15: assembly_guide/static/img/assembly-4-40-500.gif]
Higher Lower assembly


**Purchase:** [Higher Lower Game DIY Electronics Kit](https://www.oskitone.com/product/higher-lower-game-diy-electronics-kit)

## What you'll be making

Higher Lower is a 3D-printed, screen-free, handheld electronic game about arbitrary musical intervals.

This guide walks you through how to solder and assemble it, step by step. It will take 30 minutes or so, not counting 3D-printing time.

More behind-the-scenes info on Higher Lower and its development process: [https://blog.tommy.sh/posts/higher-lower/](https://blog.tommy.sh/posts/higher-lower/).

### How to play "Higher Lower"

Two different tones play. Is the second tone _higher_ or _lower_ than the first? The more guesses you get right, the harder it gets!

- Four guesses per round, ten rounds per game. Any wrong guess and the game resets.
- Your score is how many rounds have passed, and it's announced after each round as a series of happy trill noises.
- For a multiplayer game, hand off to the next player after each round. The last player to successfully complete their round wins.
- At the start of each new game, the "Higher Lower" theme song plays. It is a very good song.
- Upon completing all ten rounds of guesses and winning the game, the theme plays again, faster and _faster_ and **_faster_** until the machine finally resets into a new game at a harder difficulty setting.
- Adjust volume and game difficulty by opening the enclosure and adjusting trim potentiometers on the PCB.

<div style={{padding:"56.25% 0 0 0",position:"relative"}}><iframe src="https://player.vimeo.com/video/1075918437?badge=0&amp;autopause=0&amp;player_id=0&amp;app_id=58479" frameborder="0" style={{position:"absolute",top:0,left:0,width:"100%",height:"100%"}} allow="autoplay; fullscreen; picture-in-picture; clipboard-write; encrypted-media"  title="Higher Lower game demo"></iframe></div><script src="https://player.vimeo.com/api/player.js"></script>

### Disclaimers

You've been warned!

:::note
This kit requires through-hole soldering and takes about 30min to assemble. If you bought it without 3D-printed parts, you will need to print them yourself.
:::

:::warning
Not a toy. Choking hazard. Small parts. Not for children under 3 years.
:::

## About this guide

To save cost, trees, and frustration from outdated information, printed instructions are not included by default with Oskitone kits. This online guide will always be up to date and the best source of information for how to assemble your new toy.

Thank you for understanding!

:::note
If you run into any problems with your build or something in the guide seems incorrect, please [please _email_ me to let me know](https://www.oskitone.com/contact)! I'll do my best to help you, and your feedback will help improve the guide and other future Oskitone designs.
:::

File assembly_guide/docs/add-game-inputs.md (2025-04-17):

---
id: add-game-inputs
title: Add game inputs
description: Connecting switch inputs to play Higher Lower
sidebar_label: Add game inputs
image: /img/switch_push_to_test-019.jpg
slug: /add-game-inputs
---

:::note
Take your time and make sure the switches are perfectly flat against the PCB before soldering all of their pins.
:::

## Step(s)

1. Solder SPST switches to **SW2** and **SW3**.
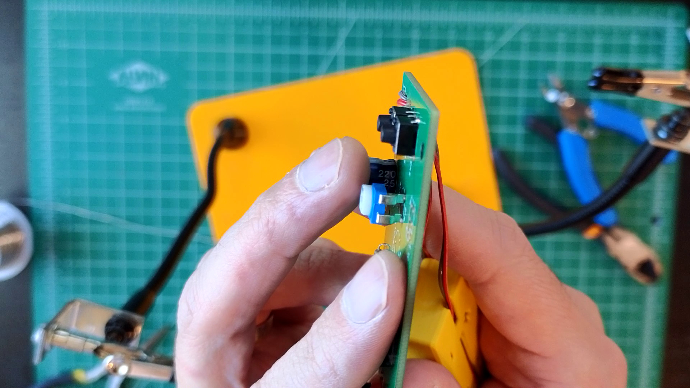
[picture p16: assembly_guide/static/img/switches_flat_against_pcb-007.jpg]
switches flat against pcb
   
   Make sure they're absolutely flat against the PCB before soldering all of their pins.

## Test

With board powered, pressing either **SW2** or **SW3** plays more tones out of the speaker and flashes **D1**.

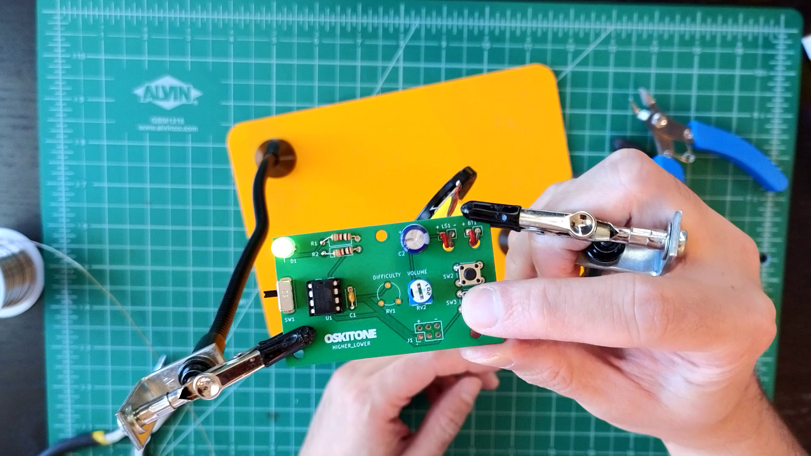
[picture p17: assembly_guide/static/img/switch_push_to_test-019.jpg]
switch push to test


Not working as expected? Check the [PCB troubleshooting](pcb-troubleshooting.md) section. Otherwise, continue.

## How it works

These kinds of switches are SPST, or Single-Pole Single-Throw. Despite having four pins, they're about as simple as a switch can be. When pressed, an internal connection is closed; when it's not pressed, it's open. Both sides of that connection have two pins, so there're four pins total.

**SW2** and **SW3** connect to two input pins on the **ATtiny85**.

The inputs are "held high" by the microcontroller, meaning that there's a small current of positive voltage on them. But pressing a switch instead brings them low to ground, and that voltage change can be interpreted by the **ATtiny85** as a button press. Pretty cool!

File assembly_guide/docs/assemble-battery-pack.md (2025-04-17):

---
id: assemble-battery-pack
title: Assemble battery pack
description: How to assemble Higher Lower's battery pack
sidebar_label: Assemble battery pack
image: /img/battery_terminal_dual_contact-003.jpg
slug: /assemble-battery-pack
---

:::note
Your ribbon cable may have different colors from the pictures here, and that's okay! A common convention is to use the darker color for "-" and the lighter one for "+".
:::

## Steps

1. Insert tabbed battery contact terminals
   1. The flat, button contact goes near "+". Its button should face inward towards where the battery will be.
   2. These tabbed contacts will have a tight fit! Use pliers to push them in if you need to.
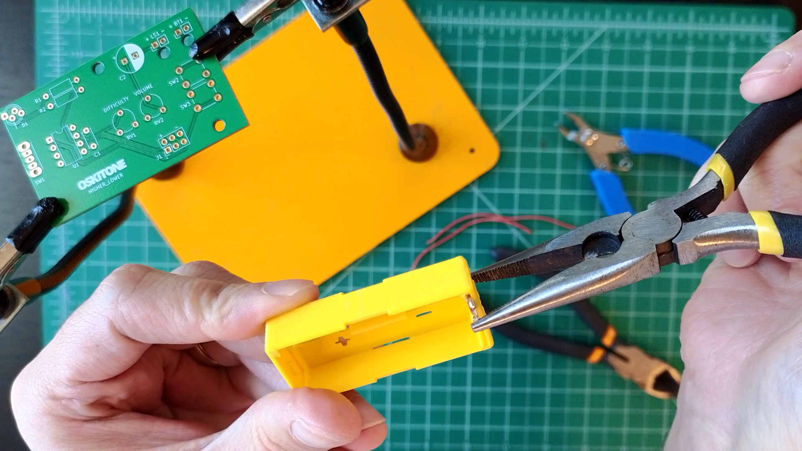
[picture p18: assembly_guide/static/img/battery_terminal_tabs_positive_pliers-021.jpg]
battery terminal tabs positive pliers
      
   3. The springed contact goes to the spot with a "-".
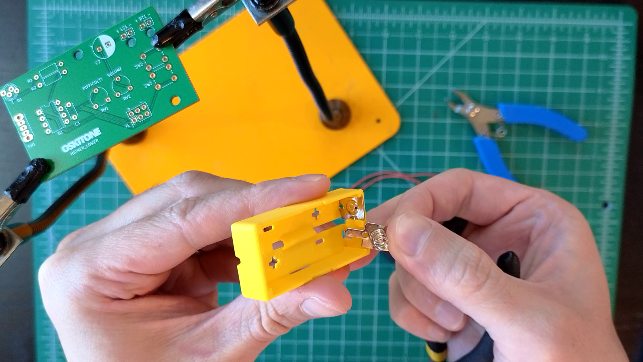
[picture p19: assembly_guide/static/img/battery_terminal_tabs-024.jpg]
battery terminal tabs
      
2. Insert dual contact wire terminal
   1. This one is a made of a solid piece of wire. Again, spring goes to "-" and button to "+".
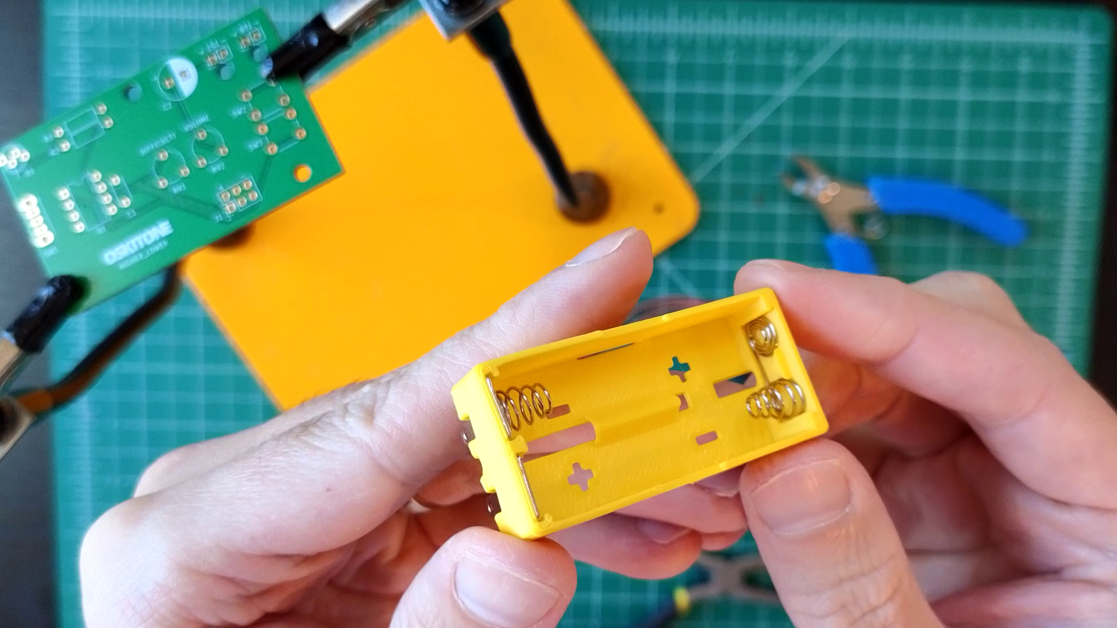
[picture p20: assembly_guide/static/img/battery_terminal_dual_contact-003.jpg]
battery terminal dual contact
      
3. Add wire
   1. Cut your ribbon cable in half so its two pieces measure about 5" each.
   2. Thread the 5" ribbon cable through the relief hitch on the bottom of the battery holder.
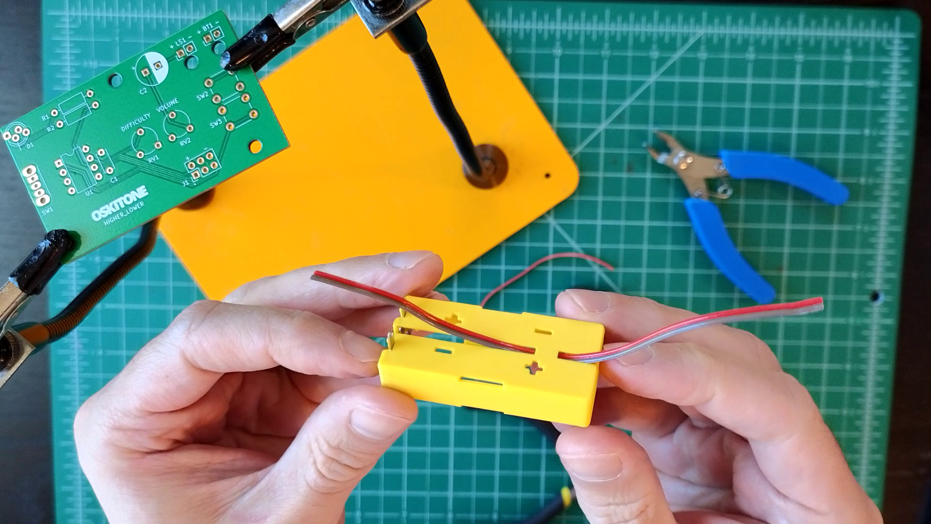
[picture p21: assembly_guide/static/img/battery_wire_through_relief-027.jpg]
battery wire through relief
      
4. Solder
   1. On the side of the cable closer to the battery contact tabs, separate the two wires and strip off 1/4" of insulation.
   2. Solder the darker wire to the "-" spring tab and the lighter wire to the "+" button tab. Try not to melt the battery holder's plastic!
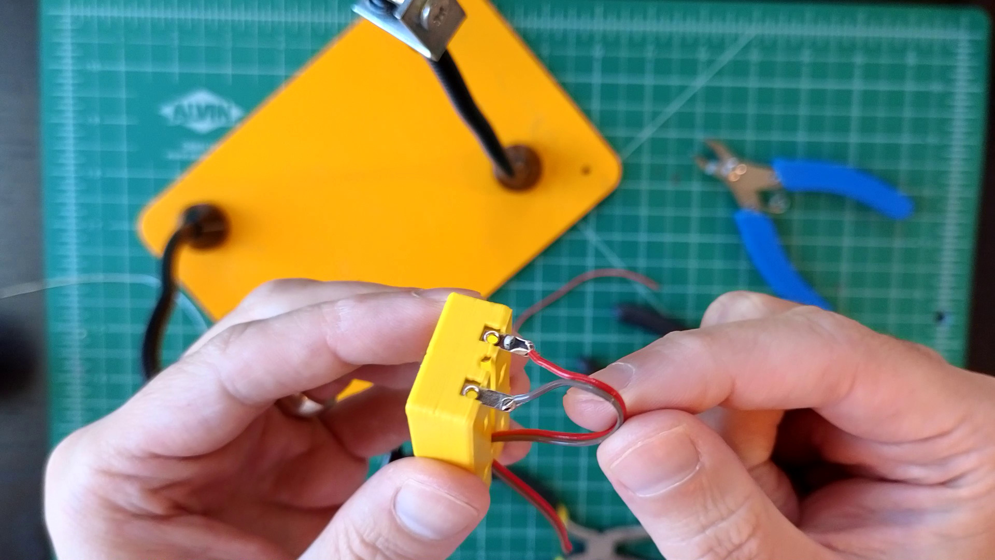
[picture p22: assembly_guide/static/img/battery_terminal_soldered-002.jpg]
battery terminal soldered
      
   3. Bend soldered terminal tabs up.
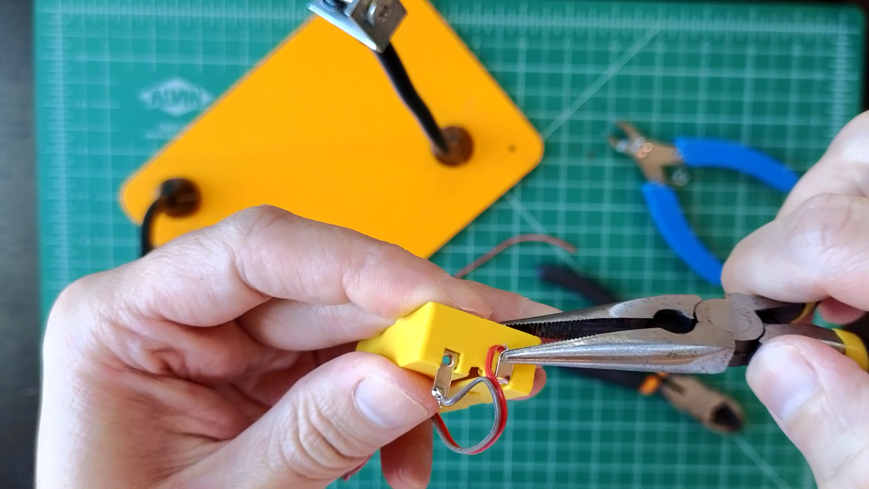
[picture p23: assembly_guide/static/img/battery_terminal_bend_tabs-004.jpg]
battery terminal bend tabs
      
   4. Pull the cable back and away from the soldered tabs until it's taut.
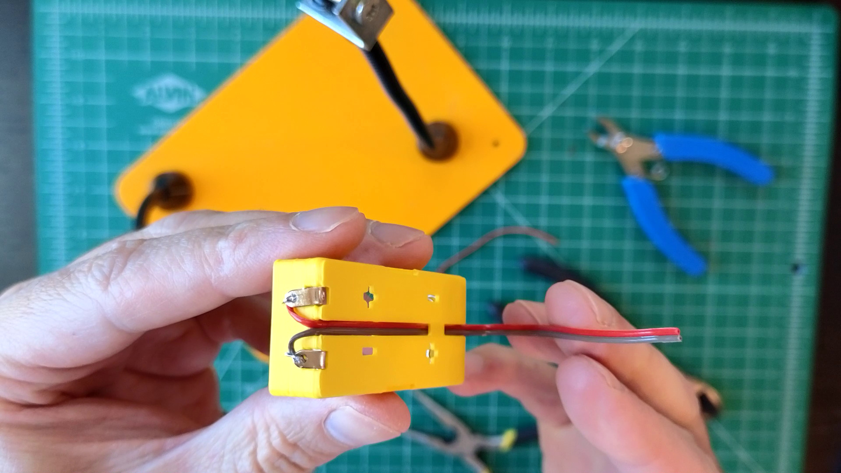
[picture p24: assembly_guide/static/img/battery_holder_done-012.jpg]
battery holder done
      
   5. Separate and strip the other side of wires.
   6. Make sure the two wires don't touch. Then, insert two AAA batteries, matching their "+" and "-" sides to the battery holder's labels.

## Test

Using a multimeter, measure the total voltage on those two wires. It should measure the sum of the two individual batteries' voltages &mdash; ideally 2.4 to 3, depending on what kind of batteries they are.

:::tip
After testing, remove one or both batteries to prevent accidentally draining them if the battery holder's wires should touch.
:::

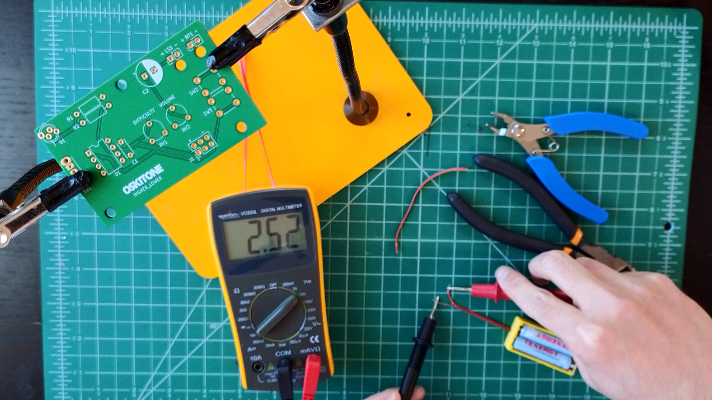
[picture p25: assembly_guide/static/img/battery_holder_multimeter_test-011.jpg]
battery holder multimeter test


If you're having trouble with your multimeter, try measuring each battery individually and see if they have voltage individually as you expect. Then install them into the battery pack and check their combined voltage.

Not working as expected? Check the [PCB troubleshooting](pcb-troubleshooting.md) section. Otherwise, continue.

## How it works

In this battery holder, the ribbon cable connects to two sides of the two different batteries with the tabbed terminals, which are connected to each other with the wire terminal.

Connecting batteries like this adds their voltages together. So if one fully charged AAA battery has 1.5 volts, then two will have 3v (shorthand for 3 volts), three will have 4.5v, and so on.

The game uses two AAA batteries, and the rechargeable Ni–MH ones I'm using in the picture have about 1.25v each, so the final output voltage is around 2.5v (1.25 &times; 2). Yours may add up to 3v or maybe even a little more, depending on the batteries' chemistry.

This kind of wiring is called "in serial." Think "one after the other," like episodes of a show or trains on a car. It's the most common way you'll see battery packs.

In contrast to serial wiring is "parallel," where all the "+" sides of the batteries connect and all the "-" sides separately connect. The output voltage is the same as just one of the batteries, but they last much longer. Parallel-wired battery packs are much less common.

<!-- Schematically, the battery pack you just made looks like this:

TODO -->

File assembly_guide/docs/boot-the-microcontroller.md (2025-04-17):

---
id: boot-the-microcontroller
title: Boot the microcontroller
description: How to get the Higher Lower's microcontroller working and booted up
sidebar_label: Boot the microcontroller
image: /img/test_microcontroller-028-60.gif
slug: /boot-the-microcontroller
---

## Steps

1. Solder **U1** socket. It will have a dimple at one end, which should match the footprint on the PCB.
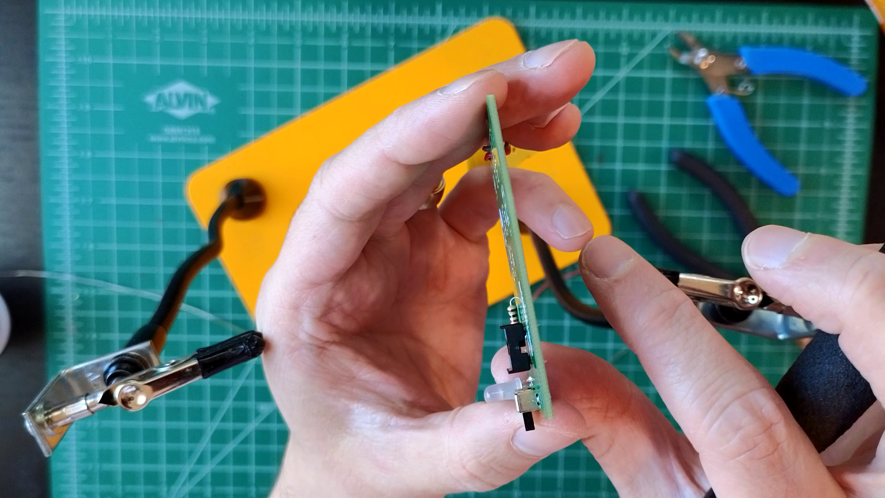
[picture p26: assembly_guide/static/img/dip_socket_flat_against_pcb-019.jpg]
dip socket flat against pcb
   
   Verify the socket is perfectly flat against the PCB before soldering all of its pins. If it's not flat and you try pushing it in, you can accidentally pop out a pin &mdash; not good!
1. Solder capacitor **C1** (.1uF, marked 104) and resistor **R2** (1k, Brown Black Red).
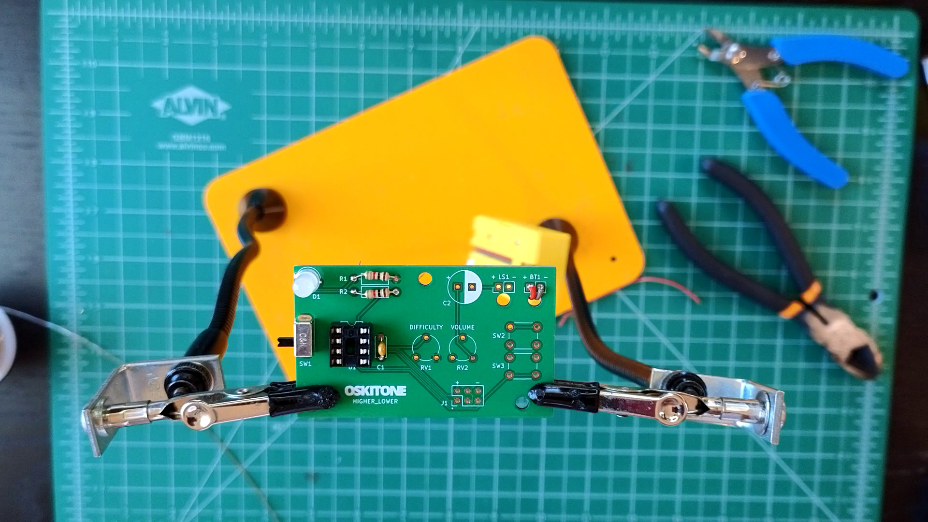
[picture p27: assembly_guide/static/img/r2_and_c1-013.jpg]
r2 and c1
   
1. If necessary, bend the pins of the **ATtiny85** IC chip so that they're parallel to each other, like this:
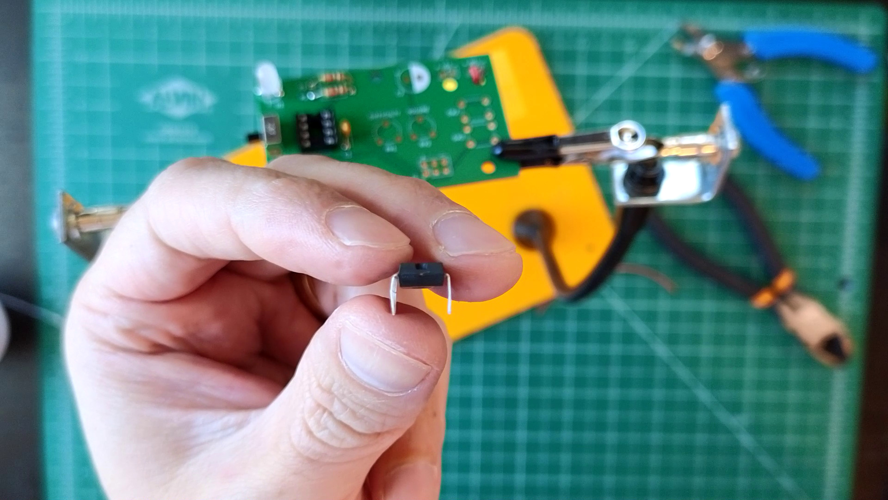
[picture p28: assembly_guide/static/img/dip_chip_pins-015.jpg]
dip chip pins
   
1. With the power off, carefully insert the **ATtiny85** IC chip. It will have a dimple (and/or a small dot in a corner), which should match the socket.
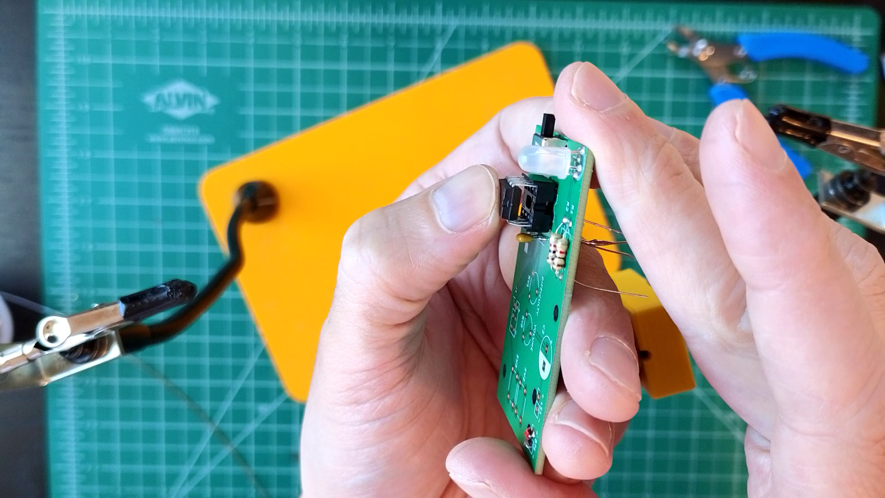
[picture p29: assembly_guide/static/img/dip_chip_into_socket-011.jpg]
dip chip into socket
   

## Test

Turn the power switch back on, and the LED should flash a new color. This lets you know that the chip is booted up and running! Power off.

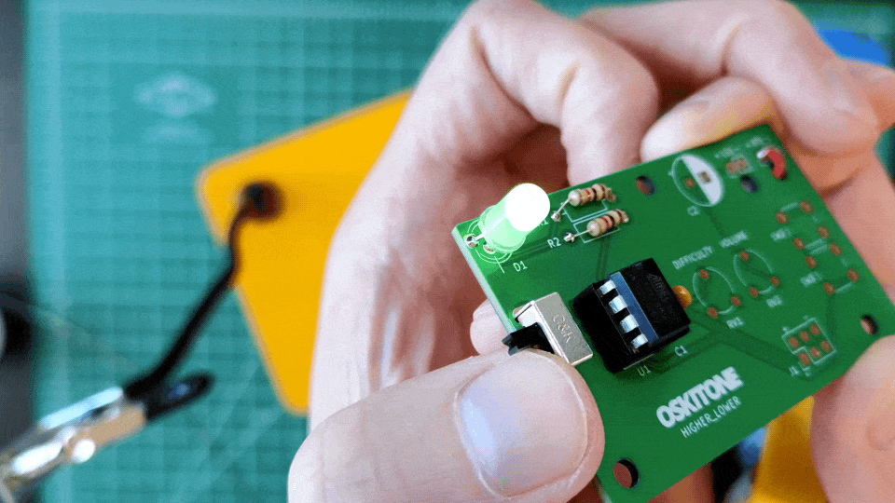
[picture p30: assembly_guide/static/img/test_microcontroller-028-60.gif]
test_microcontroller-028-60


Not working as expected? Check the [PCB troubleshooting](pcb-troubleshooting.md) section. Otherwise, continue.

## How it works

The **ATtiny85** is a microcontroller chip. Think of it like a small computer that's programmed to only do a very specific job.

This **ATtiny85**'s job is to perform the logic to play "Higher Lower." It's the brains of the operation. A small part of that operation is to flash the red color on the RGB LED, newly connected by **R2**.

(If you're curious if _all_ **ATtiny85**s can play "Higher Lower", the answer unfortunately is that they do not. The one in your kit came preprogrammed just for this game.)

**C1** is a decoupling capacitor, also known as a bypass cap. It smooths out the power for the ATtiny85 so it's less affected by spurious voltage changes as the circuit operates. Bypass caps are used a lot in electronics near components that use/make bursts of voltage, which would otherwise result in audible noise or random logical glitches. They're often not practically necessary but are a good preventative measure.

Similarly, the socket that the chip plugs into isn't _strictly_ necessary. The **ATtiny85** could just as well be soldered directly to the board. But what happens if the chip gets damaged from excessive heat during the soldering process or somehow gets fried from bad a connection? A socket lets you swap chips without melting any solder.

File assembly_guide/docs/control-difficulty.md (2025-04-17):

---
id: control-difficulty
title: Control difficulty
description: Add a pot to control Higher Lower's difficulty setting
sidebar_label: Control difficulty
image: /img/rv1-021.jpg
slug: /control-difficulty
---

## Step(s)

1. Solder trimpot **RV1** (10k, marked "103")
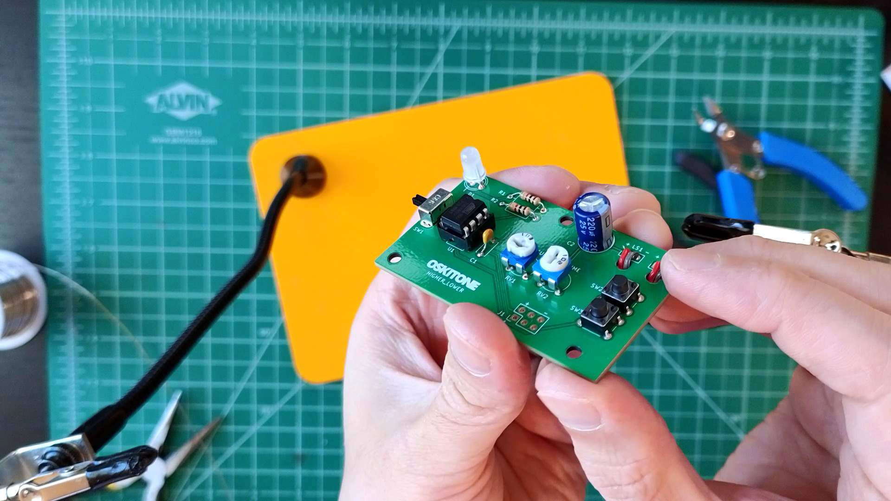
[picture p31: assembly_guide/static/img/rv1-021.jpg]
rv1
   
   Make sure it's pushed all the way into PCB before fully soldering.

## Test

Changing **RV1**'s value _before powering the board_ changes the game's difficulty. Try different rotations and count the number of intro beeps before the theme song plays.

More beeps = harder game!

Not working as expected? Check the [PCB troubleshooting](pcb-troubleshooting.md) section. Otherwise, continue.

## How it works

We know that **RV1** is a variable resistor or potentiometer, like **RV2** for volume control. We also know that pins on the **ATtiny85** can be wired as inputs, like **SW2** and **SW3** for game controls.

**RV1** is tied to an input pin on the chip, but how does it work if the input is controlled by a pot instead of a button?

The first part of the answer is that a potentiometer is technically _two_ variable resistors, and any two or more resistors can be wired as a circuit called a "voltage divider". The outer two legs of the pot connect to voltage and ground; depending on where it's turned, the middle leg is some voltage in between.

The second part of the answer is that there are two kinds of inputs on the **ATtiny85**:

- A **digital** input accepts either high ("+" or 3v from the batteries) _or_ low ("-" or 0v).
- An **analog** input accepts the full range of possible voltages from high _to_ low: 0v to 3v and all the semi-voltages in between. (How granular the possible values can be depends on a machine inside the chip called an Analog-to-Digital Converter or ADC.)

So **RV2** is wired as a voltage divider running into an analog input. The chip's ADC maps the incoming analog voltage to five discrete possible values, 0 to 4, which the code uses to set how hard the game will be.

(And, as you may have guessed, the game control switch inputs are digital.)

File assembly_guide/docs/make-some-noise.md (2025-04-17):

---
id: make-some-noise
title: Make some noise
description: How to start getting noises out of Higher Lower
sidebar_label: Make some noise
image: /img/test_speaker-022.jpg
slug: /make-some-noise
---

## Steps

1. Solder trim potentiometer (aka "trimpot") **RV2** (1k, marked "102").
   - Make sure **RV2** is pushed all the way into PCB before soldering all of its pins.
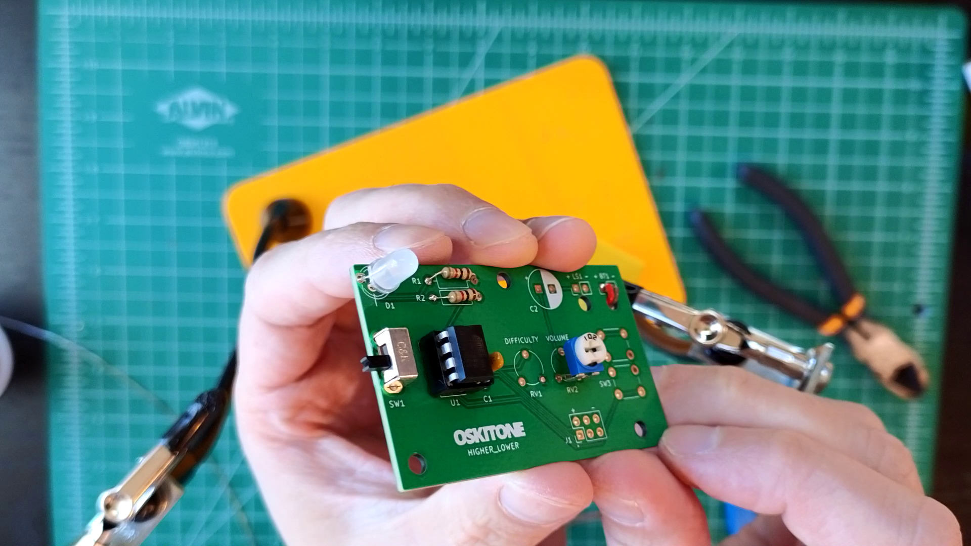
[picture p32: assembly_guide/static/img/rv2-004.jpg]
rv2
     
2. Wire speaker to **LS1**.
   1. Thread remaining piece of ribbon cable through the hole by **LS1**.
   2. Separate wires and strip 1/4" of insulation, then solder to **LS1**.
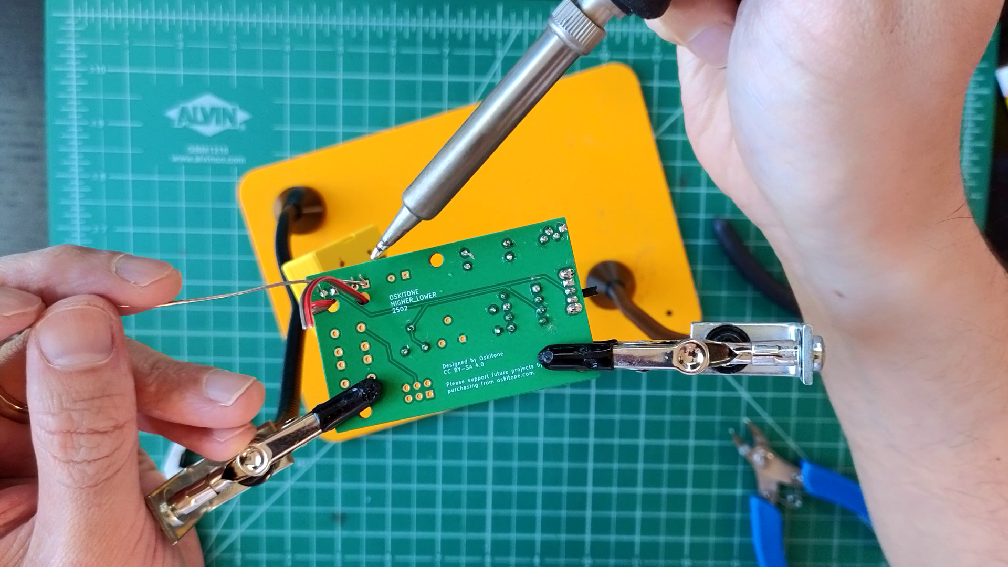
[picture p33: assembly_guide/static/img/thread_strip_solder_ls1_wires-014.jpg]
thread strip solder ls1 wires
      
   3. Strip and solder the other ends to the speaker, matching the "+" and "-" sides.
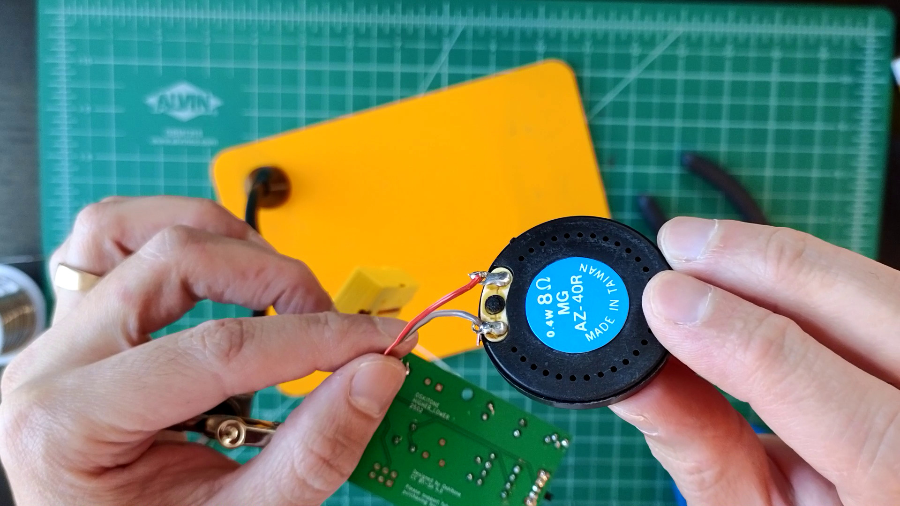
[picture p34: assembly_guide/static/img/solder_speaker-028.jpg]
solder speaker
      
3. Solder capacitor **C2** (220uF).
   - **C2** has polarity. Match its white side to the white side of its footprint.
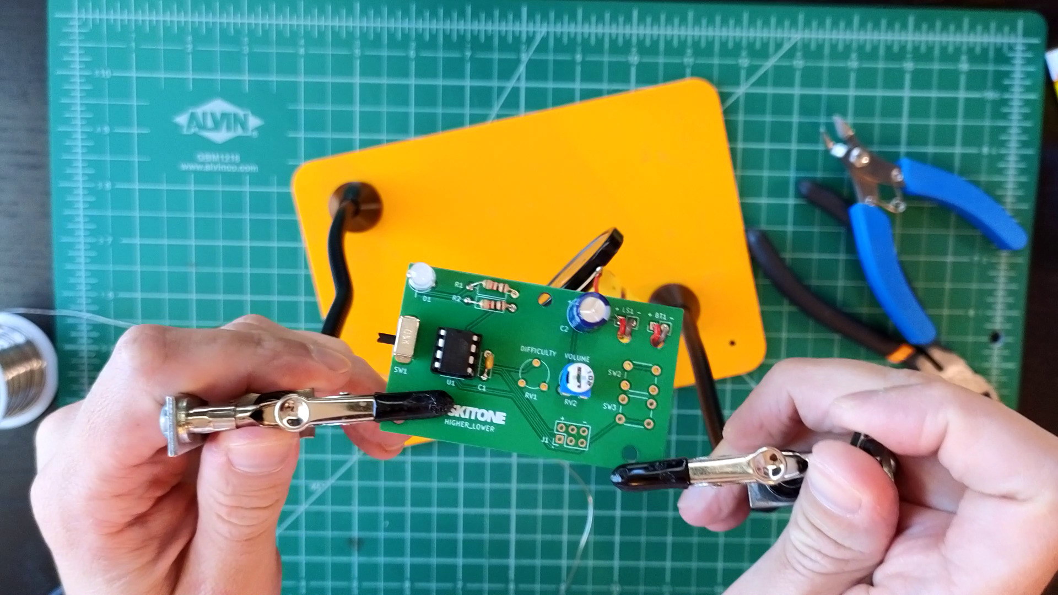
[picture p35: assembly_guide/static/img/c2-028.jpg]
c2
     

## Test

Sliding **SW1** to power the board, a little tune plays out of the speaker. This is the "Higher Lower" game theme song!

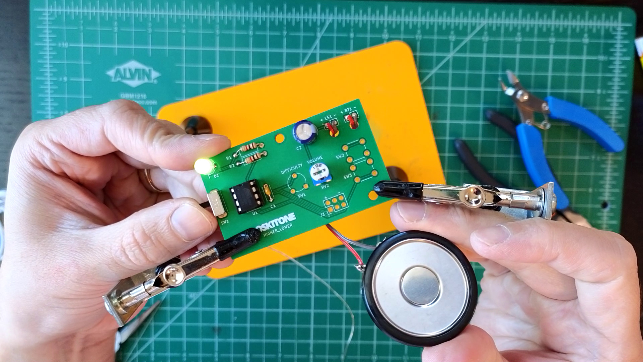
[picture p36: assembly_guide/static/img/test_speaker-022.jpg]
test speaker


Adjust **RV2** with a screwdriver for volume control.

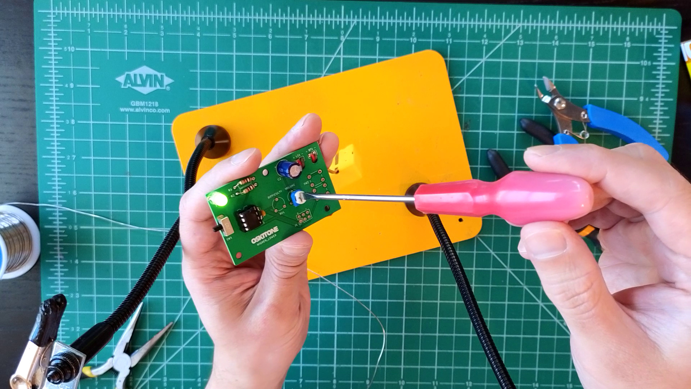
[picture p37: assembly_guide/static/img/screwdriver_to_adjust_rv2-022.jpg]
screwdriver to adjust rv2


Not working as expected? Check the [PCB troubleshooting](pcb-troubleshooting.md) section. Otherwise, continue.

## How it works

One of the pins on the **ATtiny85** is tasked with outputting square waves by quickly alternating between low and high voltage.

It connects to variable resistor **RV2**, which works the same way that the **R1** resistor did when you lit the LED: it limits current. The _variable_ part of **RV2** means that how much it limits is set by turning its dial. A higher resistance (measured in Ω or "ohms") means a smaller current which means a quieter sound from the speaker.

Variable resistors are called potentiometers (or "pots"), and small potentiometers like these are trimmers (or, adorably, "trimpots").

**C2** is a coupling capacitor. Think of it like a big bucket that fills up with voltage before dumping it at the speaker.

When that voltage drives an electromagnet that vibrates a cone inside the speaker, it creates ripples in the air that eventually reach your ears as sound waves.

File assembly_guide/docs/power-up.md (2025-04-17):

---
id: power-up
title: Power up
description: Getting power to Higher Lower's PCB and toggling an LED
sidebar_label: Power up
image: /img/reinsert_battery_and_flip_switch_to_test-008-r-60.gif
slug: /power-up
---

:::tip
The SPST switch has very short legs and won't stay in the PCB, making it tricky to solder. You can use a bit of tape to hold it in place as you solder. See the [general tips](general-tips) section for other advice.
:::

## Steps

1. Wire battery pack to **BT1**
   1. Thread the loose end of the ribbon cable connected to the battery pack up through the hole near **BT1**.
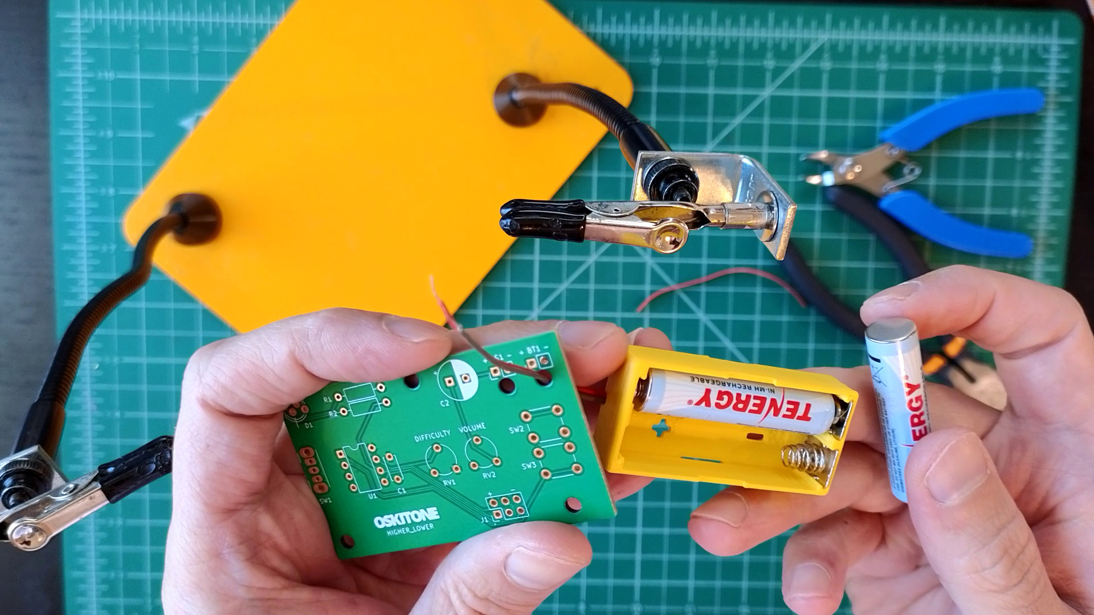
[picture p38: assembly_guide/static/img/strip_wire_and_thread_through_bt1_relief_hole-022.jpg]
strip wire and thread through bt1 relief hole
      
   2. Strip its wires and solder in place. Make sure the "+" and "-" wires are going to the right places.
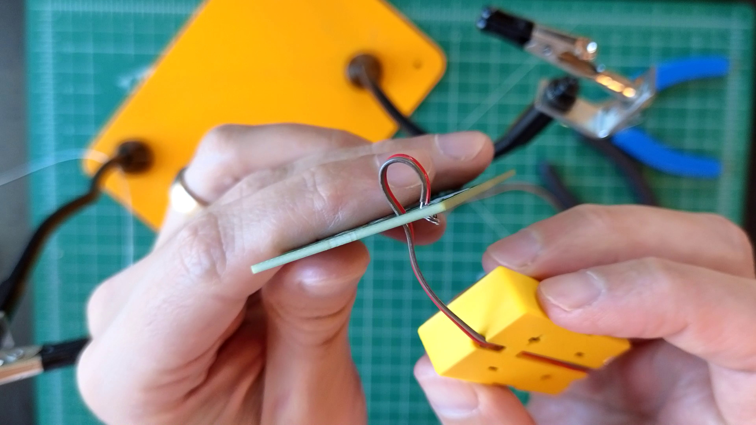
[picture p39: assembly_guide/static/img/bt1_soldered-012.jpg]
bt1 soldered
      
2. Solder RGB LED at **D1**
   1. The LED has four pins for three different colors plus ground. The longest one is to ground and it goes to the hole that has a line coming out of it.
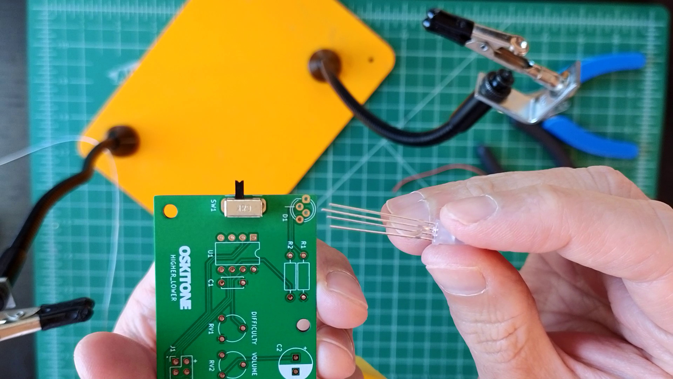
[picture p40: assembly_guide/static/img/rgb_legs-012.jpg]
rgb led
      
   2. Push the LED into the PCB as far as you can; it doesn't have to be flat against the PCB but does need to be straight up and down &mdash; no leaning!
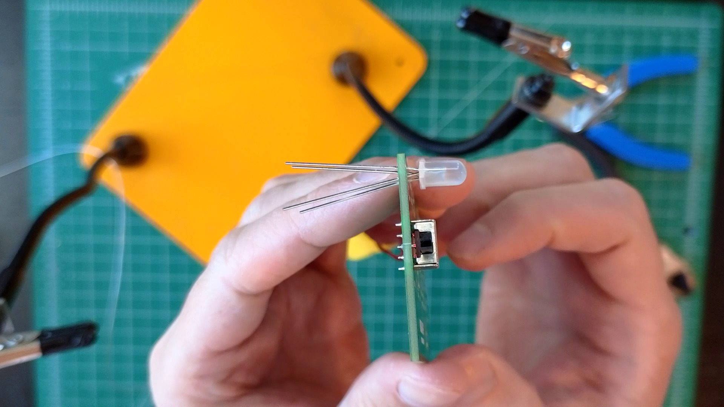
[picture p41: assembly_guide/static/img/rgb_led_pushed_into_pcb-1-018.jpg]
rgb led pushed into pcb
      
3. Solder sliding toggle switch **SW1** and resistor **R1** (1k, Brown Black Red).
   1. Make sure the switch is flat against the PCB and its actuator is pointing left, away from the PCB.
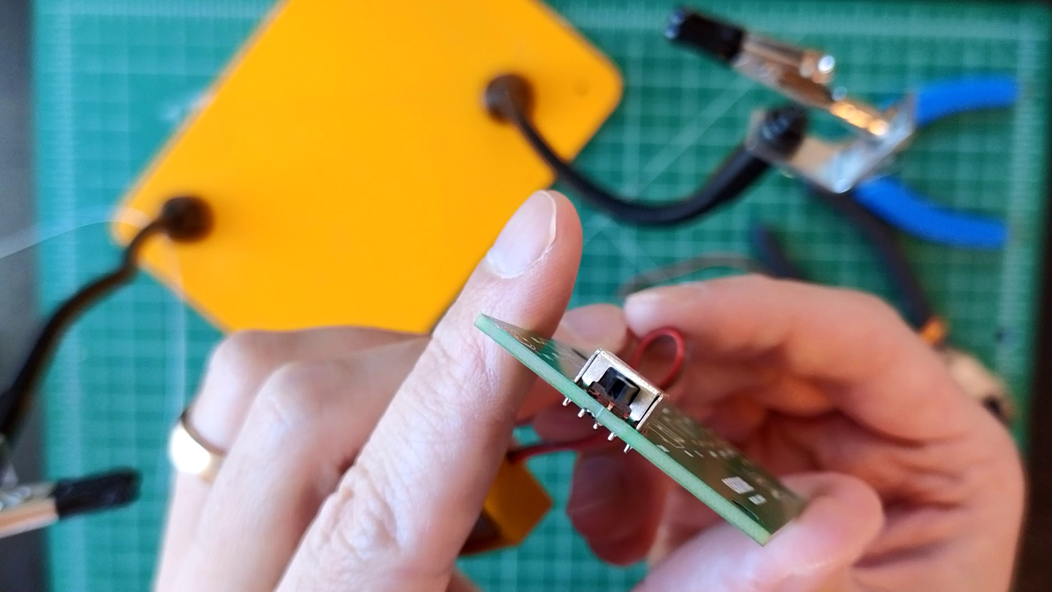
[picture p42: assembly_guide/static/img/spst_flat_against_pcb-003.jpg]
spst flat against pcb
      

## Test

Add the batteries back into the battery holder. Toggling **SW1** should now light one color of the LED! Power off before continuing soldering.

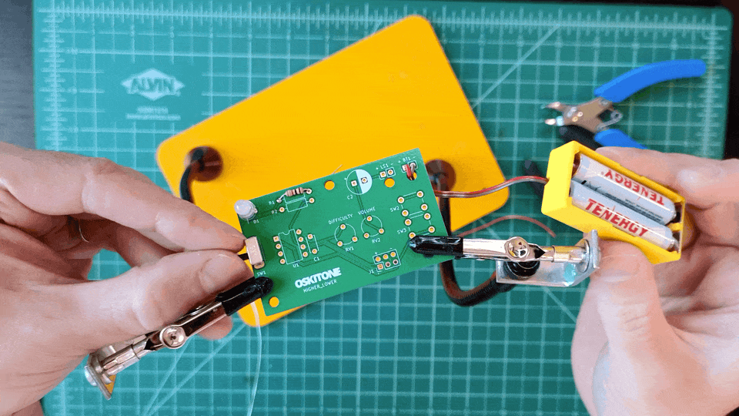
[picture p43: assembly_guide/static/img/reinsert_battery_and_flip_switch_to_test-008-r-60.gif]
reinsert battery and flip switch to test


Not working as expected? Check the [PCB troubleshooting](pcb-troubleshooting.md) section. Otherwise, continue.

## How it works

<!-- Let's start with "What even is an RGB LED?"

LED stands for Light Emitting Diode. A diode is a component that only allows electricity to move through it in one direction, and LEDs are diodes that light up. Typically, LEDs only shine specific colors, like the red one on your TV or the annoying bright white one on your electric toothbrush. -->

An RGB LED is a **L**ight-**E**mitting **D**iode with three pins for the colors **R**ed, **G**reen, and **B**lue.

This RGB LED is common cathode, so the longest pin goes to ground (the "-" side of the battery). The other kind of RGB LED is common anode, where the longest pin goes high to voltage (the "+" side of the battery).

LEDs can burn out if they're supplied too much electricity. While there's not much risk of that with just the two AAA batteries, the resistor at **R1** limits the current supplied to prevent burnout and, more importantly, make sure the LED doesn't shine too bright.

Toggling **SW1** completes the circuit so that electricity can flow from the battery, through the resistor, to the LED, and finally back into the battery.

<!-- TODO: schematic -->

<!-- - VCC means "Voltage Common Collector," a technical way to say the "+" side of our batteries
- GND means "Ground," or the batteries' "-" side
- So we have VCC going through a current-limiting resistor into the green pin of the RGB LED and then finally into GND -->

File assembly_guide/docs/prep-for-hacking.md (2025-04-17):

---
id: prep-for-hacking
title: Prep for hacking
description: Optionally solder the parts required to change the Higher Lower's code
sidebar_label: Prep for hacking
image: /img/tape_on_j1_header-003.jpg
slug: /prep-for-hacking
---

:::note
If you have no intention of ever changing the game's code, you can skip this part and it will work perfectly fine. But, you know, you're here, so you might as well!
:::

## Steps

1. Solder **J1** header.
   - Try to get it flat against PCB, as usual. Here, I'm using some tape to hold in in place.
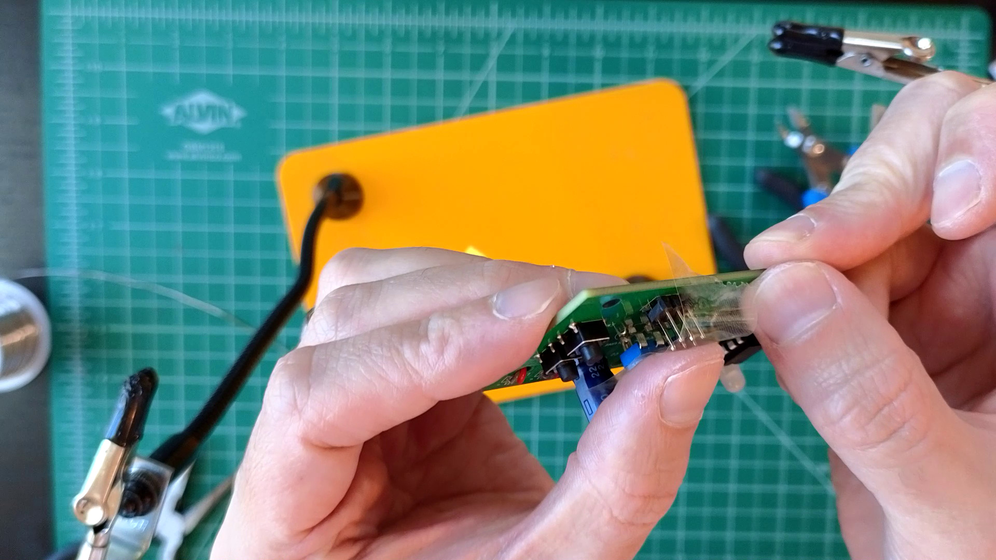
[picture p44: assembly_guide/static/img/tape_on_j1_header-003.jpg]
tape on j1 header
     

## <del>Test</del> All done?!

This one is harder to test, but if you've got it soldered and all the previous steps' tests passed, you're good to go!

:::note No but really
J1 is a header that connects to a programmer, letting you upload new code to the microcontroller. Code and basic usage are described in the [project's github repo](https://github.com/oskitone/higher_lower). It's a bit advanced, so, for now, it's been left out of the assembly guide.

Please [_email_ me to let me know](https://www.oskitone.com/contact) how it goes or if you need any help.
:::

## How it works

The 2x3 header at J1 connects to six pins on the ATtiny85 used for In-Circuit Serial Programming (ICSP), a method for updating a chip's functionality without having to send it back to the factory.

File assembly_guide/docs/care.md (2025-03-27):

---
id: care
title: Care
sidebar_label: Care
image: /img/final_product_1-004.jpg
---

- 3D-printed plastic is susceptible to warping under hot temperatures. Keep it out of prolonged direct sunlight.
- When the device seems to reset randomly while playing (or doesn't turn on at all!), that's a sign that its batteries don't have enough voltage. [Open up the enclosure](opening-the-enclosure.md) and replace them.

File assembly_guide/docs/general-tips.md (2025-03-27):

---
id: general-tips
title: General tips and getting started
description: Things to keep in mind as you solder your Higher Lower game
sidebar_label: General tips and getting started
image: /img/dip_socket_tape-021.jpg
slug: /general-tips
---

:::note
Take your time and be patient! If you run into a problem, try to keep a cool head and refer to the [PCB troubleshooting](pcb-troubleshooting.md) section. If your problem remains unfixed and you can't figure it out, [please _email_ me to let me know](https://www.oskitone.com/contact)! I'll do my best to help you, and your feedback will help improve the guide and other future Oskitone designs.
:::

## General tips

- **Component colors**<br />
  This guide's components' brands and body colors (and even the PCB color itself) may look different from yours, and that's okay! What's important is that the part types and values are in the right spots.
- **Resistors are labeled with colors, capacitors with numbers**<br />
  Resistors' values are marked as colored bands on their body. Ceramic capacitors use a number system to denote their value.
- **Ceramic and electrolytic capacitors**<br />
  There are two kinds of “caps” used in this kit. Ceramic capacitors are small, circular, and have no polarity; they can be placed in either direction. Electrolytic caps are bigger, cylindrical, and have marked +/- polarities.
- **ICs in sockets**<br />
  Each IC chip comes with a corresponding socket with the same number of pins. You will solder the socket to the PCB, not the chip itself. This prevents overheating the IC with the soldering iron and makes it easier to switch a faulty one out.
- **Component polarities**<br />
  LEDs, batteries, and electrolytic capacitors have positive and negative leads. Where applicable, the PCB will be labeled where each lead goes or a component outline to denote orientation.
- **IC orientation**<br />
  The IC chips also have an orientation, marked by a notch at their top. Make sure these line up when soldering the sockets and again when inserting the chips. A chip can be permanently damaged if inserted incorrectly!
- **Get tricky/sticky with short-lead components**<br />
  Components with short leads can be hard to get to stay on the PCB, because you can't really bend their leads to get them to stay put. But there are tricks! Try using tape or "Blu-Tack" adhesive to hold them.
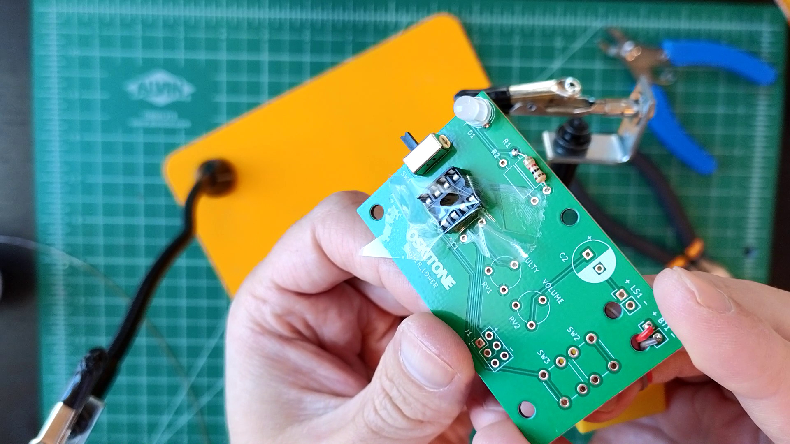
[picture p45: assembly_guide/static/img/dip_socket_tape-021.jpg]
dip socket tape
  
  Or, clip the solder into your "holding hands", and try bringing the _board to the solder_ (instead of the typical reverse of solder to board).
- **Components flat against PCB**<br />
  Many of the PCB's components need to be perfectly flat against the board for the final assembly. You'll see extra callouts in the instructions when that's important.

## Let's get started!

For reference, we'll end up with something like this when we're done:

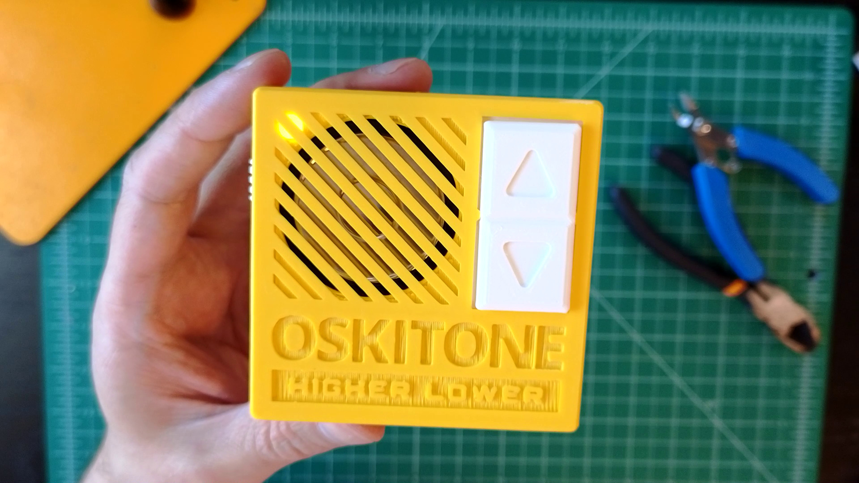
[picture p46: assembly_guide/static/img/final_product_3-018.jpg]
Higher Lower, final product


### How this guide is organized

Each group of steps in this guide has a test at the end to make sure everything you just did is working as expected, ie: "Make sure the LED lights up", "Make sure the microcontroller works", "Make sure the speaker has sound", etc.

If it doesn't work, don't fret! Look over the [PCB troubleshooting](pcb-troubleshooting.md) tips. Don't move on in the instructions until you've got the test working.

:::note Note for the experienced/impatient
The guide's steps are intentionally ordered. If you don't want to follow the guide, that's okay! But it may be harder to debug later if anything doesn't work as expected.
:::

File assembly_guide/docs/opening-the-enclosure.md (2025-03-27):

---
id: opening-the-enclosure
title: Opening the enclosure
description: How to open up the Higher Lower's enclosure after it's snapped together
sidebar_label: Opening the enclosure
image: /img/enclosure_open_wedge-027.jpg
slug: /opening-the-enclosure
---

There are two ways to do this:

- Insert a flathead screwdriver (or similar flat tool) into one of the horizontal gaps where the enclosure's halves meet, then twist and wedge apart.
  enclosure open wedge
- Squeeze the sides of the enclosure bottom, as indicated by the dimple marks, then pull apart.
  enclosure open dimple

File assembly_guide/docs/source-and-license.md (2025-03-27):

---
id: source-and-license
title: "Source and License"
description: Higher Lower is open-source hardware.
image: /img/final_product_1-004.jpg
sidebar_label: Source and License
---

## Source

Higher Lower is open-source hardware.

[https://github.com/oskitone/higher_lower](https://github.com/oskitone/higher_lower)

## License

> Designed by Oskitone. Please support future projects by purchasing from [Oskitone](https://www.oskitone.com/).
>
> Creative Commons Attribution/Share-Alike, all text above must be included in any redistribution. See license.txt for additional details.


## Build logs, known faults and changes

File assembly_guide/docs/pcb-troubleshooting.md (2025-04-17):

---
id: pcb-troubleshooting
title: PCB troubleshooting
description: Common problems that come up when soldering the Higher Lower PCB
sidebar_label: PCB troubleshooting
image: /img/final_product_1-004.jpg
slug: /pcb-troubleshooting
---

## General tips

Any of these problems can cause a variety of "just not working right" errors in a circuit. Familiarize yourself with these troubleshooting checks and do them regularly.

- Are the batteries installed and wired to the board correctly? Make sure the "+" and "-" wires are going to the right places.
- Turn the PCB over and check all solder joints. A majority of problems are caused by insufficient or errant soldering. Familiarize yourself with what a good joint looks like in the [Adafruit Guide To Excellent Soldering](https://learn.adafruit.com/adafruit-guide-excellent-soldering).
- Is the chip all the way in and in the right orientation? Its dimple should match the footprint outline on the PCB.
- Do the batteries have enough power? The two batteries should have a total voltage of 2.4 to 3 volts. If the game seems like it's restarting a lot as you play it, that's a good sign the batteries need replacing.
- If there’s buzzing, check for any metal scraps stuck to the speaker.
- If the buttons are touchy or behaving weird, check to see that their switches are inserted all the way and perfectly flat against the PCB.
- If you're hearing an unwanted hum from the speaker when the game isn't being played, verify C1 cap is soldered well. It may also be from noise added by long wires, so do use the recommended wire lengths in this guide.
- If the volume or difficulty trimpots aren't behaving as expected, check to see that they're both in the right place and not swapped.

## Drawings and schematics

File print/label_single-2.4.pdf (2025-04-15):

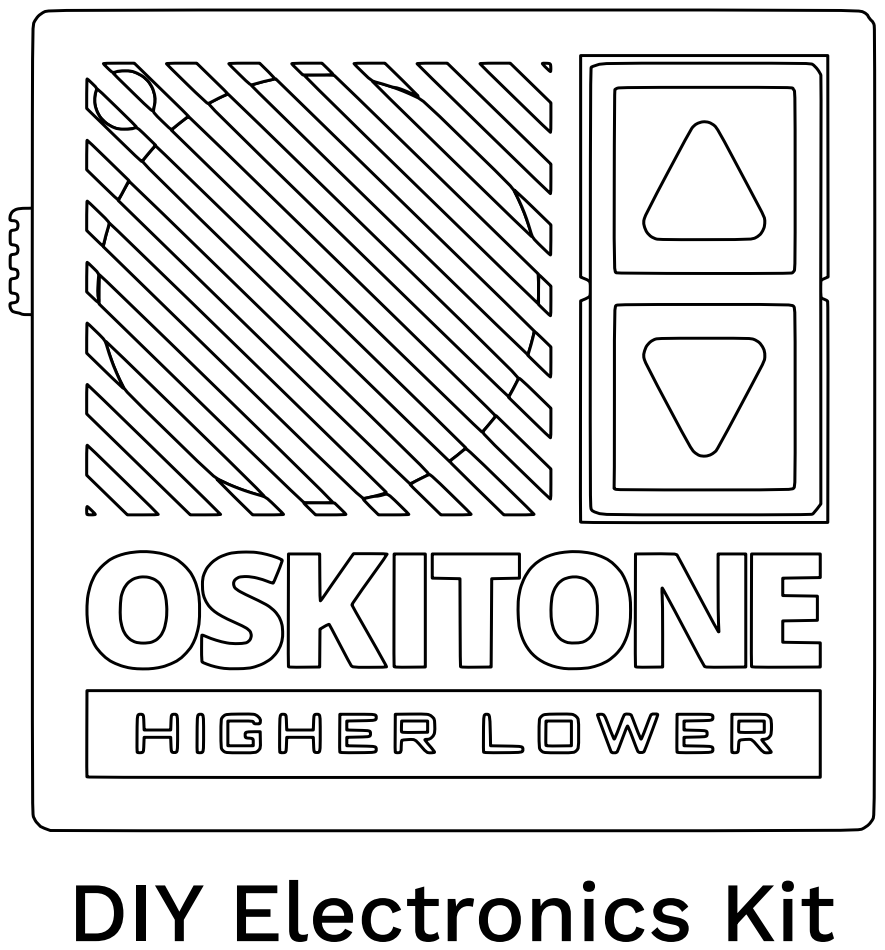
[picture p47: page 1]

DIY Electronics Kit

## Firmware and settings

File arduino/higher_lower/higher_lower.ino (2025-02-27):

#include "consts.h"
#include "interface.h"
#include "noise.h"

#include "game.h"

void setup() {
  setupInterface();
  setupSerial();

  _delay(bootPause);

  reset();
}

void loop() {
  if (justPressed(Intent::DOWN)) {
    handleGuess(Intent::DOWN, tones[index] < tones[index - 1]);
  }

  if (justPressed(Intent::UP)) {
    handleGuess(Intent::UP, tones[index] > tones[index - 1]);
  }

  if (justPressed(Intent::SKIP)) {
    handleGuess(Intent::NONE, true, true);
  }
}

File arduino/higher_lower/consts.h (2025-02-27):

#ifdef __AVR_ATtiny85__
const int outputPin = 4;
const int ledPin = 1;
const int upPin = 0;
const int downPin = 3;
const int ctrlPin = A1;
const int skipPins[3] = {-1, -1, -1};
#else
const int outputPin = 5;
const int ledPin = 9;
const int upPin = A0;
const int downPin = A3;
const int ctrlPin = 8;
const int skipPins[3] = {A1, 7, 8};
#endif

const int themeNoteLength = 180;

// NOTES: max human-audible frequency is ~20k and max for int16_t is ~32k,
// but this max is the max that doesn't hurt my ears.
const int minTone = 60;
const int maxTone = 1000;

const int guessesPerRound = 4;
const int roundsPerGame = 10;

const int tonesPerRound = (guessesPerRound + 1);

// NOTE: Yes, we start at 1 instead of 0,
// because we want an interval between tones.
// Ya can't diff off nuthin, charlie!
const int startingIndex = 1;

const int lastToneDuration = themeNoteLength * 4;
const int currentToneDuration = (lastToneDuration / 2);
const int minToneOrIntervalPauseDuration = 8;

const int bootPause = 250;
const int resetPause = 1000;
const int postButtonPressPause = 250;
const int newRoundPause = 500;
const int preIntervalPause = themeNoteLength / 2;
const int midIntervalPause = preIntervalPause / 2;

const int intervalChunk = ((maxTone - minTone) / tonesPerRound);
const int minInterval = 2;

const float intervalDiminish = .65;
const float durationDiminish = .85;
const float themeMotifSpeedup = 1.125;

const int minStartingDifficulty = 0;
const int maxStartingDifficulty = 4;

// NOTE: For emulation, in lieu of analog input
const int defaultDifficulty = 0;

enum Intent { NONE, UP, DOWN, SKIP };

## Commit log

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2024-09-06 Refine "chunk" and prevent its crashes
    [higher_lower.ino]
2024-09-07 Tighten durations/intervals as rounds progress
    And give an out to skip whole rounds
    [higher_lower.ino]
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2024-09-11 Fix "0 frequency" tones
    It being after failure was coincidental
    [higher_lower.ino]
2024-09-12 Rewrite getNextTone
    * Simplify args
    * Ditch constrain(), rely on MIN/MAX check
    * Fix possibly seemingly incorrect "GUESSES_PER_ROUND - " math
    * Make multiplier accumulative. It should be like rolling
    multiple dice and adding their sums, not rolling one and then
    multiplying it.
    Imperfect but better
    [higher_lower.ino]
2024-09-12 Prevent stagnant scale tones
    [higher_lower.ino]
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2024-09-13 Get bare ATtiny85 process working
    wuddadoozy
    1. Lots of issues despite Digispark, which uses
    10mhz attiny85 in SMD format, working fine.
    2. Tiny AVR Programmer wasn't responsive and no
    blinking lights anywhere, even though
    multimeter confirmed chip was getting power.
    Trying the actual Damellis/ATtiny board
    Sparkfun recommends in the hookup guide seemed
    to get it working. Able to upload blink
    3. Uploaded game code and looked like it was
    blinking at about the same rate as blink
    example. Why?
    4. On top of that, silent speaker output. Tried
    386 and different pins. Turns out the "ATtiny"
    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
    [higher_lower.kicad_sch]
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2024-09-14 Update schematic
    * Programming: 2x3 header
    * Power: battery, switch, PWR_FLAG, header
    * Connections: redundant headers for switches,
    move skip into header, expose reset
    [higher_lower.kicad_sch]
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2024-09-14 Fix stuck tones around round 21
    When duration is 0, it plays forever...
    [common.h]
2024-09-14 Fix negative overflow at round 255/2
    Round unceremoniously resets to 0 at 256, which is
    unexpected but preferable to an all-out crash
    [higher_lower.ino]
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2024-09-14 Update schematic
    * Borrow power switch, RGB, audio jack from Scout
    * Commit to having an LED
    * Add crude volume control
    [higher_lower.kicad_sch]
2024-09-17 Fix schematic after soldering
    * Fix RGB pin order
    * Buttons go to GND, not VCC
    [higher_lower.kicad_sch]
2024-09-20 Copy over wub openscad
    [enclosure.scad, higher_lower.scad, pcb.scad]
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2024-09-22 Correct battery and use
    [enclosure.scad, higher_lower.scad]
2024-09-22 Tidy upfront dimension math
    [higher_lower.scad]
2024-09-22 Derive PCB dimensions and use
    [enclosure.scad, higher_lower.scad, pcb.scad]
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2024-09-22 Make it a square?!
    [higher_lower.scad]
2024-09-22 Refine speaker/rocker preview
    and update rocker fillet to look nice still
    [button_rocker.scad, higher_lower.scad]
2024-09-22 Fix rocker brim vs enclosure wall
    [button_rocker.scad, higher_lower.scad]
2024-09-22 Redesign top engraving to fill space
    [enclosure.scad, higher_lower.scad]
2024-09-23 Warn if dimensions aren't viable, echo them out
    [higher_lower.scad, pcb.scad]
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2024-09-23 jk, enforce 2:1 grill to button ratio
    Seems unlikely I'll want something else and it's not
    worth the overhead!
    This reverts "Parameterize button_to_speaker_grill_ratio",
    commit e86c7cf3fa9b2ecfa3aad33419d69e66ec5e2987.
    [button_rocker.scad, enclosure.scad, higher_lower.scad]
2024-09-23 Size and center PCB length to speaker
    [higher_lower.scad]
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2024-09-23 Figure out where PCB switches should be
    [higher_lower.scad, pcb.scad]
2024-09-23 fixup! Size and center PCB length to speaker
    [higher_lower.scad]
2024-09-23 Contain PCB to enclosure
    [higher_lower.scad]
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2024-09-24 Account for and raise PCB to its top clearance
    [higher_lower.scad, pcb.scad]
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2024-09-24 Hack in Scout's switch_clutch
    [enclosure.scad, higher_lower.scad, pcb.scad]
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2024-09-26 Don't print the power switch
    [pcb.scad]
2024-09-26 Swap skip button for control pot
    [higher_lower.kicad_sch]
2024-09-29 Improve button_rocker preview
    Makes # easier to discern
    [button_rocker.scad, higher_lower.scad]
2024-09-29 Fix button switch center
    [higher_lower.scad, pcb.scad]
2024-09-29 Fix layout
    Previous math was imperfect, with horizontal space
    unused and jagged edges on the right. The gist of
    its problem is that you can't have a perfect 2:1
    ratio AND non-square speaker grill AND a button
    gutter AND square buttons. Just mathematically
    incompatible ideas.
    1. Ditch math to account for engraving length on
    the speaker grill, making it always square and
    the 2:1 ratio good.
    2. Fill all button_rocker space by allowing its
    buttons to be non-square, using its gutter
    correctly.
    [button_rocker.scad, enclosure.scad, higher_lower.scad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]
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2024-10-01 Decide on PCB dimensions and battery count
    * Parameterize PCB dimensions
    * Reduce battery count
    * Ditch dimension warnings
    Cool but not worth the overhead in ideation phase
    * Position PCB to speaker, not battery
    [higher_lower.scad]
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2024-10-03 Reduce PCB complexity
    * Ditch on-board headphone jack
    * Simplify off-board header connections
    [higher_lower.kicad_pcb, higher_lower.kicad_sch]
2024-10-03 Stub PCB layout draft
    [higher_lower.kicad_pcb]
2024-10-03 Nice! Layout looks good enough for demo
    [higher_lower.kicad_pcb]
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2024-10-05 Re-layout PCB w/ duped switches
    [higher_lower.kicad_pcb, higher_lower.kicad_sch]
2024-10-05 Update models for PCB
    [higher_lower.scad, pcb.scad]
2024-10-05 PCB vertical center isn't between buttons
    How, I do not know
    [higher_lower.kicad_pcb]
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2024-10-05 Add PCB fixtures to enclosure
    [enclosure.scad, higher_lower.scad]
2024-10-06 Move fastener screw away from speaker and rocker
    [enclosure.scad, higher_lower.scad, pcb.scad]
2024-10-06 Add LED to PCB
    [higher_lower.scad, pcb.scad]
2024-10-06 Use lower voltage ATtiny85V
    [higher_lower.kicad_sch]
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2024-10-08 Stub LED lightpipe exposure
    [enclosure.scad, higher_lower.scad]
2024-10-08 Use newly extracted enclosure disassembly cavities
    and constants
    [enclosure.scad]
2024-10-08 Fix enclsoure pcb_mount_post preview
    [enclosure.scad]
2024-10-09 Stub battery holder fixture
    [enclosure.scad, higher_lower.scad]
2024-10-09 Stub button supports
    Probably too brittle but fine for now
    [enclosure.scad]
2024-10-09 Enable showing non-PCB PCB stuff
    [higher_lower.scad]
2024-10-10 Plunge rocker down to buttons
    [button_rocker.scad, higher_lower.scad]
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2024-10-10 Account for tolerance in rocker cavity
    like wub
    [enclosure.scad]
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2024-10-12 Rely on enclosure snap, ditch fasteners
    [enclosure.scad, higher_lower.scad]
2024-10-12 Wrap enclosure around lightpipe
    [enclosure.scad, higher_lower.scad]
2024-10-12 Stub battery_holder top fixture
    I don't love it but let's see
    [enclosure.scad]
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2024-10-12 Increase engraving label gutter
    [higher_lower.scad]
2024-10-13 Ditch separate binary STL compression
    And, more importantly, avoid incorrect "Found no
    matches for query..." message. Avoid > Fix!
    See Scout commit 8201241629 for why it had that.
    TBD on if OpenSCAD issue is fixed.
2024-10-13 Add switch clutch fixture to enc bottom too
    [enclosure.scad]
2024-10-13 Prevent PCB vs fixture obstructions
    [enclosure.scad]
2024-10-14 Enable printing mock PCB
    [higher_lower.scad, pcb.scad]
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2024-10-15 Cavity actuators into rocker
    [button_rocker.scad, higher_lower.scad]
2024-10-15 Reduce rocker print overhang
    Debugging print failure, tho it's almost certainly
    a problem w/ my printer or filament
    UPDATE: it was but this is still a good change
    [button_rocker.scad]
2024-10-15 Refine lightpipe exposure
    * Use measured diameter and explain
    * Add outer gasket to hold it in place
    [enclosure.scad]
2024-10-18 Beef up battery_holder fixture
    Might want horizontal lip on top side too. TBD
    [enclosure.scad]
2024-10-18 Kern placard engraving to fill horizontal space
    Trying to prevent dangling bridges with STYLE
    [enclosure.scad]
2024-10-18 Refine enclosure
    * Try new fillet
    * Try real long tongue and groove
    [enclosure.scad]
2024-10-23 Tighten enclosure fit to the MAX
    Increases tongue and groove pull, measured to the
    gap between the two halves
    [enclosure.scad]
2024-10-23 Disassembly wedge > dimples
    [enclosure.scad]
2024-10-23 Update inner_fillet to inner_chamfer
    [enclosure.scad]
2024-10-23 LED isn't flush to PCB
    [enclosure.scad, higher_lower.scad, pcb.scad]
2024-10-23 Let caps be vertical
    who was i kiddin
    [pcb.scad]
2024-10-23 Ditch battery_holder fixture on top
    It was getting in the way of wires
    Try beefing up catch + friction
    Still may not be enough but worth a try
    [enclosure.scad]
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2024-10-23 Use fixed enclosure height
    And damn the clearance
    1.00787in to 1in
    [higher_lower.scad]
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2024-11-02 Theoretically, fix random seed
    But, practically and unfortunately, don't...
    Theory was that, since OUTPUT_PIN makes its way
    to GND/LOW eventually, it isn't floating enough
    to provide different HIGH/LOW values. And that's
    why, when using batteries but surprisingly not
    when using the programmer for power, we always
    seemed to get the same first interval sequence.
    UP_PIN and DOWN_PIN seem better options, since
    they float before the internal pull-downs are set
    and assuming user isn't holding their buttons.
    However, changing to UP_PIN yielded identical
    behavior.
    Not only that, but straight up using LOW did too.
    So, IDK wussup, but theoretically-improved-but-
    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
    [common.h, higher_lower.ino]
2024-11-02 Loosen rocker vertically
    Last test print was too tight and falsely actuated
    Because button_rocker_position.z is used for dimensioning, it
    should not have used e epsilon, so fix that too
    [button_rocker.scad, enclosure.scad, higher_lower.scad]
2024-11-02 Loosen rocker vertically more
    .2 was unusable. .8 is tight but workable after
    some nudging. 1 is probably good?
    [higher_lower.scad]
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2024-11-10 Don't sacrifice clearance under PCB
    [higher_lower.scad]
2024-11-10 Fix battery terminal vs fixture
    [enclosure.scad]
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2024-11-10 PCB doesn't bleed
    Introduced in commit 14c6a5cc so I could print
    a mock of the PCB. So I guess removing the bleed
    messes with that but idcrn
    [higher_lower.scad]
2024-11-11 Nudge battery_holder left some
    Partially reverts commit 84ddcf2ced45d26ee95001d98064de6874206a03.
    Flush right doesn't leave room for wires/contacts
    protruding from holder. This moves it into 2/3.
    Still plenty of room for theoretical headphone
    jack.
    [enclosure.scad, higher_lower.scad]
2024-11-11 Ditch rim around speaker exposure
    If my intent is to cover the speaker's plastic
    part, I need a little more. But now I care less
    about its cover and more about the proximity
    of the speaker to the lightpipe, so I think
    maybe no rim is the way to go. Who care?!
    [enclosure.scad]
2024-11-11 Reverse speaker grill
    [enclosure.scad]
2024-11-12 Update battery_holder back fixture
    [enclosure.scad]
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2025-01-03 Ghost PCB clearance
    [pcb.scad]
2025-01-04 Differentiate PCB clearances beyond/under speaker
    [higher_lower.scad, pcb.scad]
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2025-01-19 Try lightpipe on top
    Not yet on PCB
    [enclosure.scad, higher_lower.scad]
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2025-01-19 Derive lightpipe exposure-vs-fixture xy
    [enclosure.scad]
2025-01-19 Derive lightpipe_position too while I'm at it
    It was not as simple as using ENCLOSURE_WALL
    which is also coincidentally 2.4
    [higher_lower.scad]
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2025-01-19 Refine schematic
    * Reverse pot directions (why the footprint goes
    3-2-1 IDK but it's easier to fix in schematic)
    * Swap UP and CTRL
    * Use different LED colors
    * Remove duplicate buttons
    * Remove RESET exposure
    [higher_lower.kicad_sch]
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2025-01-19 Reverse trimpot rotations
    using new parts_cafe pot
    Incidentally update J2 (vestigial name from extra
    reset pin connector) to J1 on PCB
    [higher_lower.kicad_pcb, higher_lower.kicad_sch]
2025-01-19 Update draft PCB silkscreen model
    Aside: found the best way so far to get a good silkscreen SVG
    1. Export SVG from Kicad w/ edge cuts + front silkscreen, minimally
    2. Use "Stroke to path" in Inkscape
    3. Remove any unwanted elements
    3. Move to 0, 0 xy
    Now the question is... is there a way to automate that?
    [higher_lower.scad, pcb.scad]
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2025-01-19 Update PCB clearance under speaker
    [higher_lower.scad, pcb.scad]
2025-01-19 Fix LED vs lightpipe collision
    [higher_lower.scad]
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2025-01-19 Fix SW1 vs enclosure obstruction
    [enclosure.scad, higher_lower.scad]
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2025-01-22 Ditch PCB printing
    Partial revert of 14c6a5cc
    [pcb.scad]
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2025-01-22 Try to fix some enclosure+lightpipe problems
    * Try to fix enclosure halves' fit obstruction
    in lightpipe corner by reducing fixture height,
    starting it at LED's bottom instead of PCB's
    top. Might not be the actual fix but shouldn't
    hurt anything.
    * Try to prevent LED light bleed by thickening
    fixture wall
    [enclosure.scad]
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2025-01-24 Try reduced rocker_z_clearance again
    Measured with feeler gauge. .2 slides in fine.
    .4 fits but changes the sound of the button, which
    seems not ideal
    Basically, revert 7b8b9316b5
    [higher_lower.scad]
2025-01-24 Bring back enclosure disassembly dimples
    Now that half heights are equal
    [enclosure.scad]
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2025-01-26 Hack switch_clutch into being looseer
    Truly, this code is bad
    [higher_lower.scad]
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2025-01-27 Deobstruct lightpipe fixture vs enclosure wall
    or try to!
    [enclosure.scad, higher_lower.scad]
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2025-01-29 Refine lightpipe fixture
    * Loosen fixture inner diameter so it can't get stuck as easily
    Might be too loose!
    * Ditch PCB_Z_OFF_PCB to make fixture full available height
    * Add a _disassembly_channel to make lightpipe easier to remove and for
    visual confirmation of LED/lightipe/enclosure
    * Rotate speaker_fixture tab_cavities to expose channel
    Betrays the original intent of the enclosure-side cavity but that was
    never imperative anyway. Seems fine
    * Update cross-section X to new middle of lightpipe
    [enclosure.scad, higher_lower.scad]
2025-01-29 Be consistent in rocker's tolerance passage
    [button_rocker.scad, higher_lower.scad]
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2025-01-31 Loosen rocker fixture fit
    Print test held buttons down and seems far too
    tight.
    * Fix tolerance usage on XY
    * Reuse rocker_z_clearance for both top and bottom
    FWIW, new rocker_z_clearance of .8 is fine in
    isolation w/o fixture stuff.
    [button_rocker.scad, higher_lower.scad]
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2025-01-31 Refine lightpipe cavity
    * Try a little narrower exposure
    * Don't cut into speaker grill, maintain ceiling
    [enclosure.scad]
2025-02-01 Fix PCB vs battery_holder fixture collision
    [enclosure.scad]
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2025-02-07 Delay longer after each guess
    Seems unnecessary in emulator, but hardware rocker
    makes some acoustic noise that distracts from the
    next tones played, especially frustrating later
    in game.
    [common.h]
2025-02-08 Reduce duration diminishing effect
    Tones were too short to hear around round 5
    [common.h]
2025-02-09 Fix stuck duplicate sequences at difficulty 0
    [higher_lower.ino]
2025-02-09 Emulate difficulty 0 by default
    and enable skipping rounds
    [common.h, higher_lower.ino]
2025-02-09 Improve arduboy display
    * Fix OSKITONE kerning
    * Add more speaker
    * Add a lil LED
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2025-02-09 Try tape around LED instead of fixture
    Thus simplifying lightpipe fixture
    It could obviate it entirely if glue is taped to
    the LED, but that makes dimension fit checking
    less obvious
    [enclosure.scad, higher_lower.scad]
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2025-02-11 Try reversing ledPin
    Arduboy has it going low to light
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2025-02-20 Reduce LED brightness
    No functional changes to PCB
    [higher_lower-bom.csv, higher_lower.kicad_pcb, higher_lower.kicad_sch]
2025-02-20 Fix rocker falling out of enclosure top
    Commit 2d21c9d522 made its exposure too small
    to grip fixture, plus it's just a little too small
    anyway.
    This splits the difference and decouples the
    rocker's and switch's exposures.
    [higher_lower.scad]
2025-02-21 Update enclosure *_disassembly_wedge* parameter
    re parts_cafe commit 8ff80784c4
    [enclosure.scad]
2025-02-21 Shim lightpipe fixture
    Too loose! Let's see if this makes it better
    [enclosure.scad]
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2025-02-21 Fix enclosure fit gap around lightpipe
    * Re-measure and increase PCB_Z_OFF_PCB
    * Shorten lightpipe length to make up for it
    * Increase clearance for for lazy LED pushing-in
    * Improve how LED's leads and clearance are shown
    * Derive PCB_TOP_CLEARANCE_BEYOND_SPEAKER
    [higher_lower.scad, pcb.scad]
2025-02-27 Hide skipping
    * Make it less obvious: A+B+> instead of just >
    * Make it only for Arduboy version
    * And coincidentally fix a false trigger on '85
    [common.h, higher_lower.ino]
2025-02-27 Extract game logic, redux
    * Reverts e8f3274301b93a5eaa52829e6b1901da2708c04f
    * common -> consts
    * contain game variables
    [higher_lower.ino]
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2025-03-14 Add burn_chips script
    a la Scout
    * Ditch vestigial Arduboy port in runner
    * Enable uploading w/o recompilation
    * Add new script to wrap around ^
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
